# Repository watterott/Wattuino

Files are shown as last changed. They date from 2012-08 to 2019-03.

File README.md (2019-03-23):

# Wattuino
Arduino compatible Boards and Modules.

* [Wattuino Board Support Package](https://learn.watterott.com/arduino/watterott-boards) for Arduino IDE.
* [Documentation on learn.watterott.com](https://learn.watterott.com)
* Open-Source and released under the [Creative Commons Attribution Share-Alike License](https://creativecommons.org/licenses/by-sa/4.0/).

## Wattuino RC
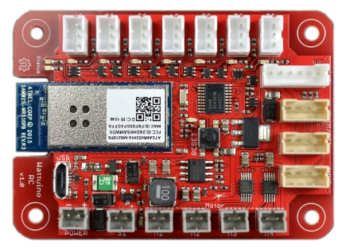
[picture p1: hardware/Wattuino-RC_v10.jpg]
Wattuino RC

* Microchip **SAMW25** Module (SAMD21 ARM Cortex-M0+ and WINC1500 WiFi/WLAN SoC)
* USB CDC+MSC Bootloader (Arduino compatible)
* 5V tolerant IOs
* Dual Full-Bridge Motor Drivers (Allegro Micro A3909)
* MicroUSB connector for programming/communication
* PCB Size: 70mm x 50mm

## Wattuino Uno
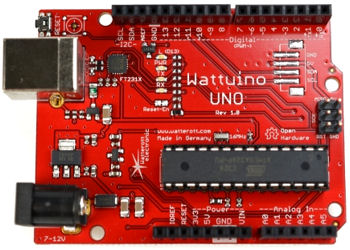
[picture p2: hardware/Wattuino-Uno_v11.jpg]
Wattuino Uno

* Microchip AVR **ATmega328P** @ 16 MHz (external resonator)
* OptiBoot Bootloader with auto baud rate detection (Arduino compatible)
* FTDI FT231X USB-UART-Bridge
* USB-B or MicroUSB connector for programming/communication
* PCB Size: 68.58mm x 53.34mm

## Wattuino Pro Mini
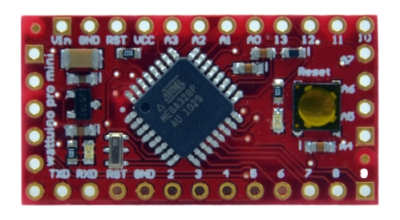
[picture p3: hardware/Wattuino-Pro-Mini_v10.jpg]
Wattuino Pro Mini

* Microchip AVR **ATmega328P** @ 16 MHz or 8 MHz (external resonator)
* OptiBoot Bootloader with auto baud rate detection (Arduino compatible)
* All pins of the AVR are available (also ADC6, ADC7)
* FTDI connector for programming/communication
* PCB Size: 33.02mm x 17.78mm

## Wattuino Pro Mini PB
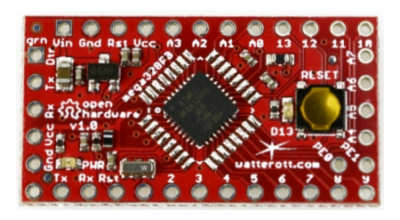
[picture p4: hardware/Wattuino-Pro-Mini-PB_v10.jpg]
Wattuino Pro Mini PB

* Microchip AVR **ATmega328PB** @ 16 MHz or 8 MHz (external resonator)
* OptiBoot Bootloader with auto baud rate detection (Arduino compatible)
* All pins of the AVR are available (also PE0/SDA1, PE1/SCL1, PE2/ADC6, PE3/ADC7)
* FTDI connector for programming/communication
* PCB Size: 33.02mm x 17.78mm

## Wattuino Nanite 841
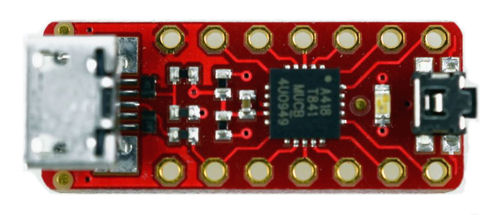
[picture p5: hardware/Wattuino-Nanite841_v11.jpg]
Wattuino Nanite841

* Microchip AVR **ATtiny841** @ 8 MHz (internal clock) with USART, SPI, I2C Slave, ADC, EEPROM
* Micronucleus USB Bootloader (Arduino compatible)
* Designed by [cpldcpu](https://github.com/cpldcpu)
* 14-Pin DIP and pin-compatible with 14-Pin SOIC ATtiny841
* MicroUSB connector for programming/communication
* PCB Size: 24.13mm x 10.16mm

## Wattuino Nanite 85
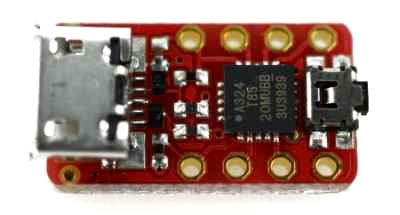
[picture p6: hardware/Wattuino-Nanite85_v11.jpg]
Wattuino Nanite85

* Microchip AVR **ATtiny85** @ 16.5 MHz (internal clock) with USI, ADC, EEPROM
* Micronucleus USB Bootloader (Arduino compatible)
* Based on the original [Nanite 85](https://github.com/cpldcpu/Nanite) design by [cpldcpu](https://github.com/cpldcpu)
* Pin-compatible with 8-Pin DIP ATtiny85
* MicroUSB connector for programming/communication
* PCB Size: 17.46mm x 10.16mm

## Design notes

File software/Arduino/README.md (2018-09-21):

# Watterott Board Support Package

Boards Package moved to (uninstall the old package before installing the new one):

```
https://github.com/watterott/Arduino-Boards/raw/master/package_watterott_index.json
```

Further infos:
https://learn.watterott.com/arduino/watterott-boards/

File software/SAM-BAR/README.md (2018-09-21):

# SAM-BAR
SAM-BAR (**S**mart **A**tmel **M**icrocontroller **B**oot **A**ssistant **R**eloaded) is a Combo USB CDC+MSD Bootloader for Atmel/Microchip SAM D21 devices (ARM Cortex-M0+).
It is based on the following bootloaders:
* [SAM-BA (AppNote AT07175) by Atmel/Microchip (www.atmel.com)](http://www.atmel.com/images/Atmel-42366-SAM-BA-Bootloader-for-SAM-D21_ApplicationNote_AT07175.zip)
* [Arduino Zero Bootloader by Arduino LLC (www.arduino.cc)](https://github.com/arduino/ArduinoCore-samd/tree/master/bootloaders/zero)
* [SAMD-MSD-Bootloader by Justin Mattair (www.mattairtech.com)](https://github.com/mattairtech/SAMD-MSD-Bootloader)

## Features
* SAM-BA and Arduino Zero compatible Bootloader (USB CDC/VCP)
* Mass-Storage-Device Bootloader (USB MSD/MSC)
* Fits in 16KB (user program start at 0x4000)

## Programming
The bootloader can be flashed with an ARM SWD (Serial Wire Debug) programmer.
To protect the bootloader flash section the fuse ```NVMCTRL_BOOTPROT``` has to be set to ```0x01```.

## Activation
The bootloader will be activated if no user program exists or by doing two reset in 0.5s (double pressing reset switch).
It can also be activated via an Arduino Sketch, when opening the serial port with 1200bps. This will erase the user program and start the bootloader.

## Usage
When the bootloader is active then a new program can be loaded via the serial port (SAM-BA protocol) or via the mass storage device.
For the mass storage device delete the file ```FLASH.BIN``` and then copy a new binary file ```FLASH.BIN``` to the drive.
After the copy process is finished, do a reset to start the new program.

On Linux/Mac the dd command can be used to write the firmware: ```dd if=NEW.BIN of=/media/BOOTLOADER/FLASH.BIN conv=notrunc```

A binary file can be generated and exported in the Arduino IDE with *Sketch->Export compiled Binary* command.

## Known Issues

### Windows
Sometimes the driver for the USB Bootloader is not loaded correctly.
Check the driver state in the Device Manager, when the Bootloader is active (double press reset).

### Linux
The Modem Manager can cause problems, because it detects Serial Ports (e.g. of the USB Bootloader) as a modem.
So we recommend to uninstall/remove the Modem Manager:
```
sudo apt-get uninstall modemmanager
```
As alternative it is also possible to add a backlist rule for the USB device to the file ```77-mm-usb-device-blacklist.rules```.

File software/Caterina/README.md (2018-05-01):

# Caterina

[Caterina](https://github.com/arduino/Arduino/tree/master/hardware/arduino/avr/bootloaders/caterina) is a small USB bootloader designed for Atmel AVR microcontrollers with USB interface (ATmega32u4).
It is based on the [LUFA library](http://www.lufa-lib.org).

The Caterina project is released under MIT license.
Code uploaded via the bootloader is not subject to any license issues.

**Credits**
```
* Arduino.cc Team
* LUFA (c) Dean Camera (dean [at] fourwalledcubicle [dot] com), www.lufa-lib.org
```

## USB Vendor and Product ID
* VID: 0x1D50 - [Openmoko](http://wiki.openmoko.org/wiki/USB_Product_IDs) + PID: 0x60B0 - [Watterott](http://wiki.openmoko.org/wiki/USB_Product_IDs)

## ISP Pins of ATmega32U4
```
MOSI: PB2
MISO: PB3
SCK:  PB1
RST:  Reset
```

## Fuse Settings for ATmega32U4
```
Extended: 0xCB
High:     0xD8
Low:      0xFF
Lockbits: 0xCF (LPM and SPM prohibited in Boot Section)
```

## AVRdude Parameters for ATmega32U4
```
avrdude -c avrisp2 -B 10 -p atmega32u4 -e -U flash:w:caterina_16mhz.hex:i -U lfuse:w:0xFF:m -U hfuse:w:0xD8:m -U efuse:w:0xCB:m -U lock:w:0xCF:m
```

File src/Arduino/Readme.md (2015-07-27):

# Watterott Board Support Package
Board Support Package for Arduino IDE >=1.6

## Automatic Installation

Add the following URL to the Arduino Boards Manager:
```
https://github.com/watterott/wattuino/raw/master/src/Arduino/package_watterott_index.json
```
and install the Watterott Boards via the Boards Manager.

## Manual Installation

Download https://github.com/watterott/wattuino/raw/master/src/Arduino/Arduino.zip and copy the directory "hardware" to your Arduino program directory.

## Known Issues

### Windows
Sometimes the driver for the USB Bootloader (Caterina or Micronucleus) is not loaded correctly.
This is the case when *Done uploading.* is not shown after the upload process.
Check the driver state in the Device Manager, when the Bootloader is active (Caterina after the *Upload* is started and Micronucleus after a reset).
On Windows 8 or higher the [driver signature enforcement](https://learn.sparkfun.com/tutorials/disabling-driver-signature-on-windows-8/disabling-signed-driver-enforcement-on-windows-8) has to be disabled for the driver installation.
* [Caterina Driver](https://github.com/watterott/wattuino/raw/master/src/Caterina/Caterina.inf)
* [Micronucleus Driver](https://github.com/watterott/wattuino/raw/master/src/Micronucleus/driver/driver.zip)
* [FTDI Drivers](http://www.ftdichip.com/Drivers/VCP.htm)

### Linux
The Modem Manager detects the Serial Ports (e.g. Caterina Bootloader) as a modem and therefore a blacklist rule is needed.
Run one of the commands - depending on your system:

```sudo nano /etc/udev/rules.d/77-mm-usb-device-blacklist.rules```
    
```sudo nano /lib/udev/rules.d/77-mm-usb-device-blacklist.rules```
    
and add the following lines to the file:

```
ATTRS{idVendor}=="6666", ENV{ID_MM_DEVICE_IGNORE}="1"
ATTRS{idVendor}=="1D50", ATTRS{idProduct}=="60B0", ENV{ID_MM_DEVICE_IGNORE}="1"
```

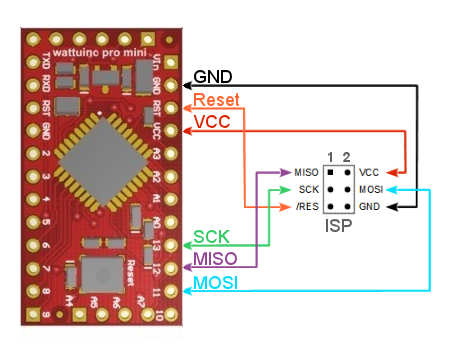
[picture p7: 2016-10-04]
hardware/Wattuino-Pro-Mini_ISP.jpg

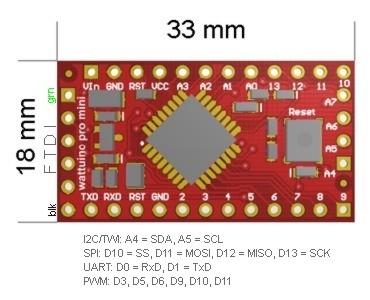
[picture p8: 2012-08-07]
hardware/Wattuino-Pro-Mini_Pins.jpg

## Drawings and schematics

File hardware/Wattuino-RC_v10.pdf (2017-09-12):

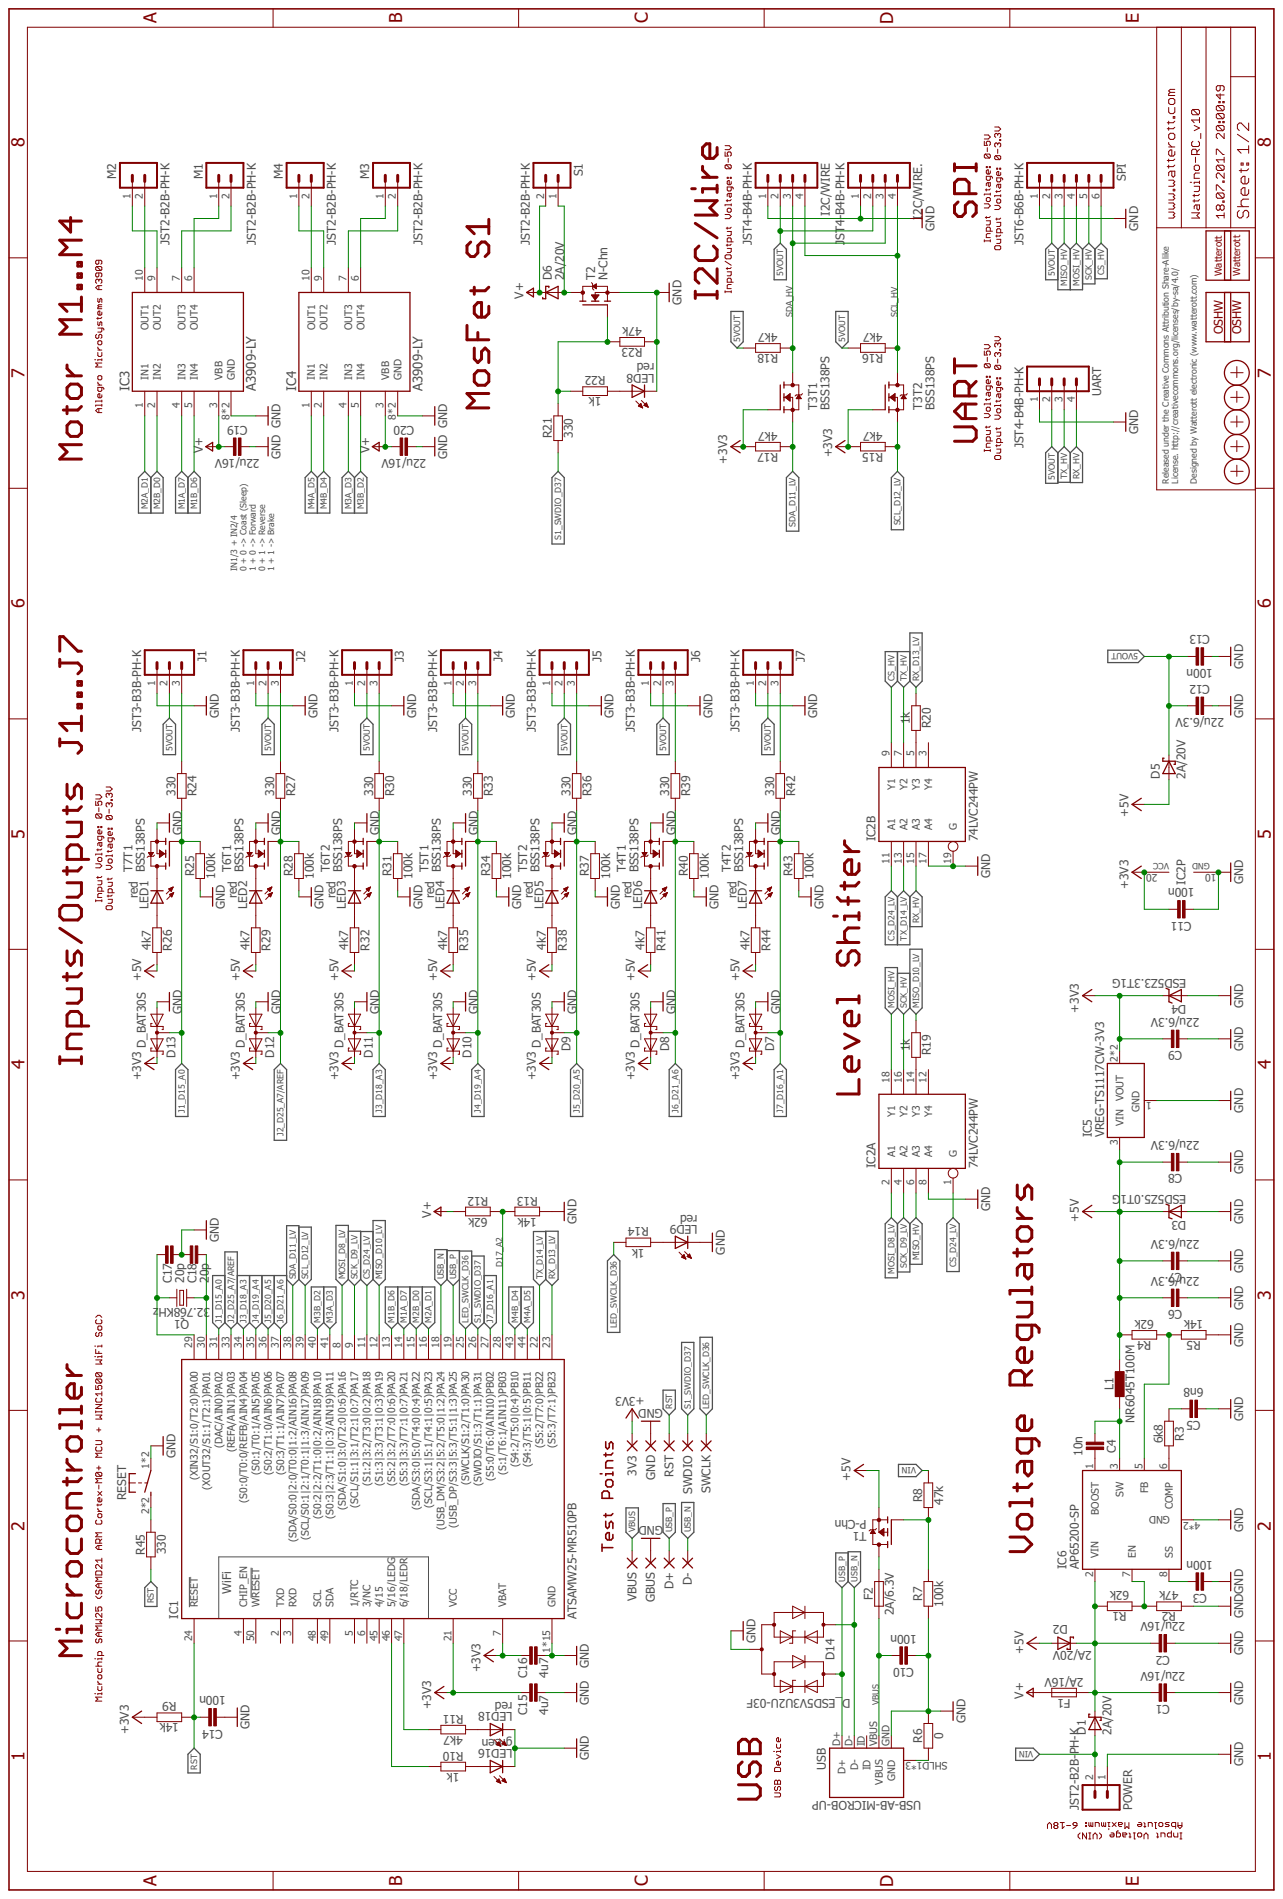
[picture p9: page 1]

Released under the Creative Commons At ribution Share-Alike

License. ht p://creativecommons.org/licenses/by-sa/4.0/ Designed by Wat erot electronic (www.wat erot .com)

GND GND GND GND GND

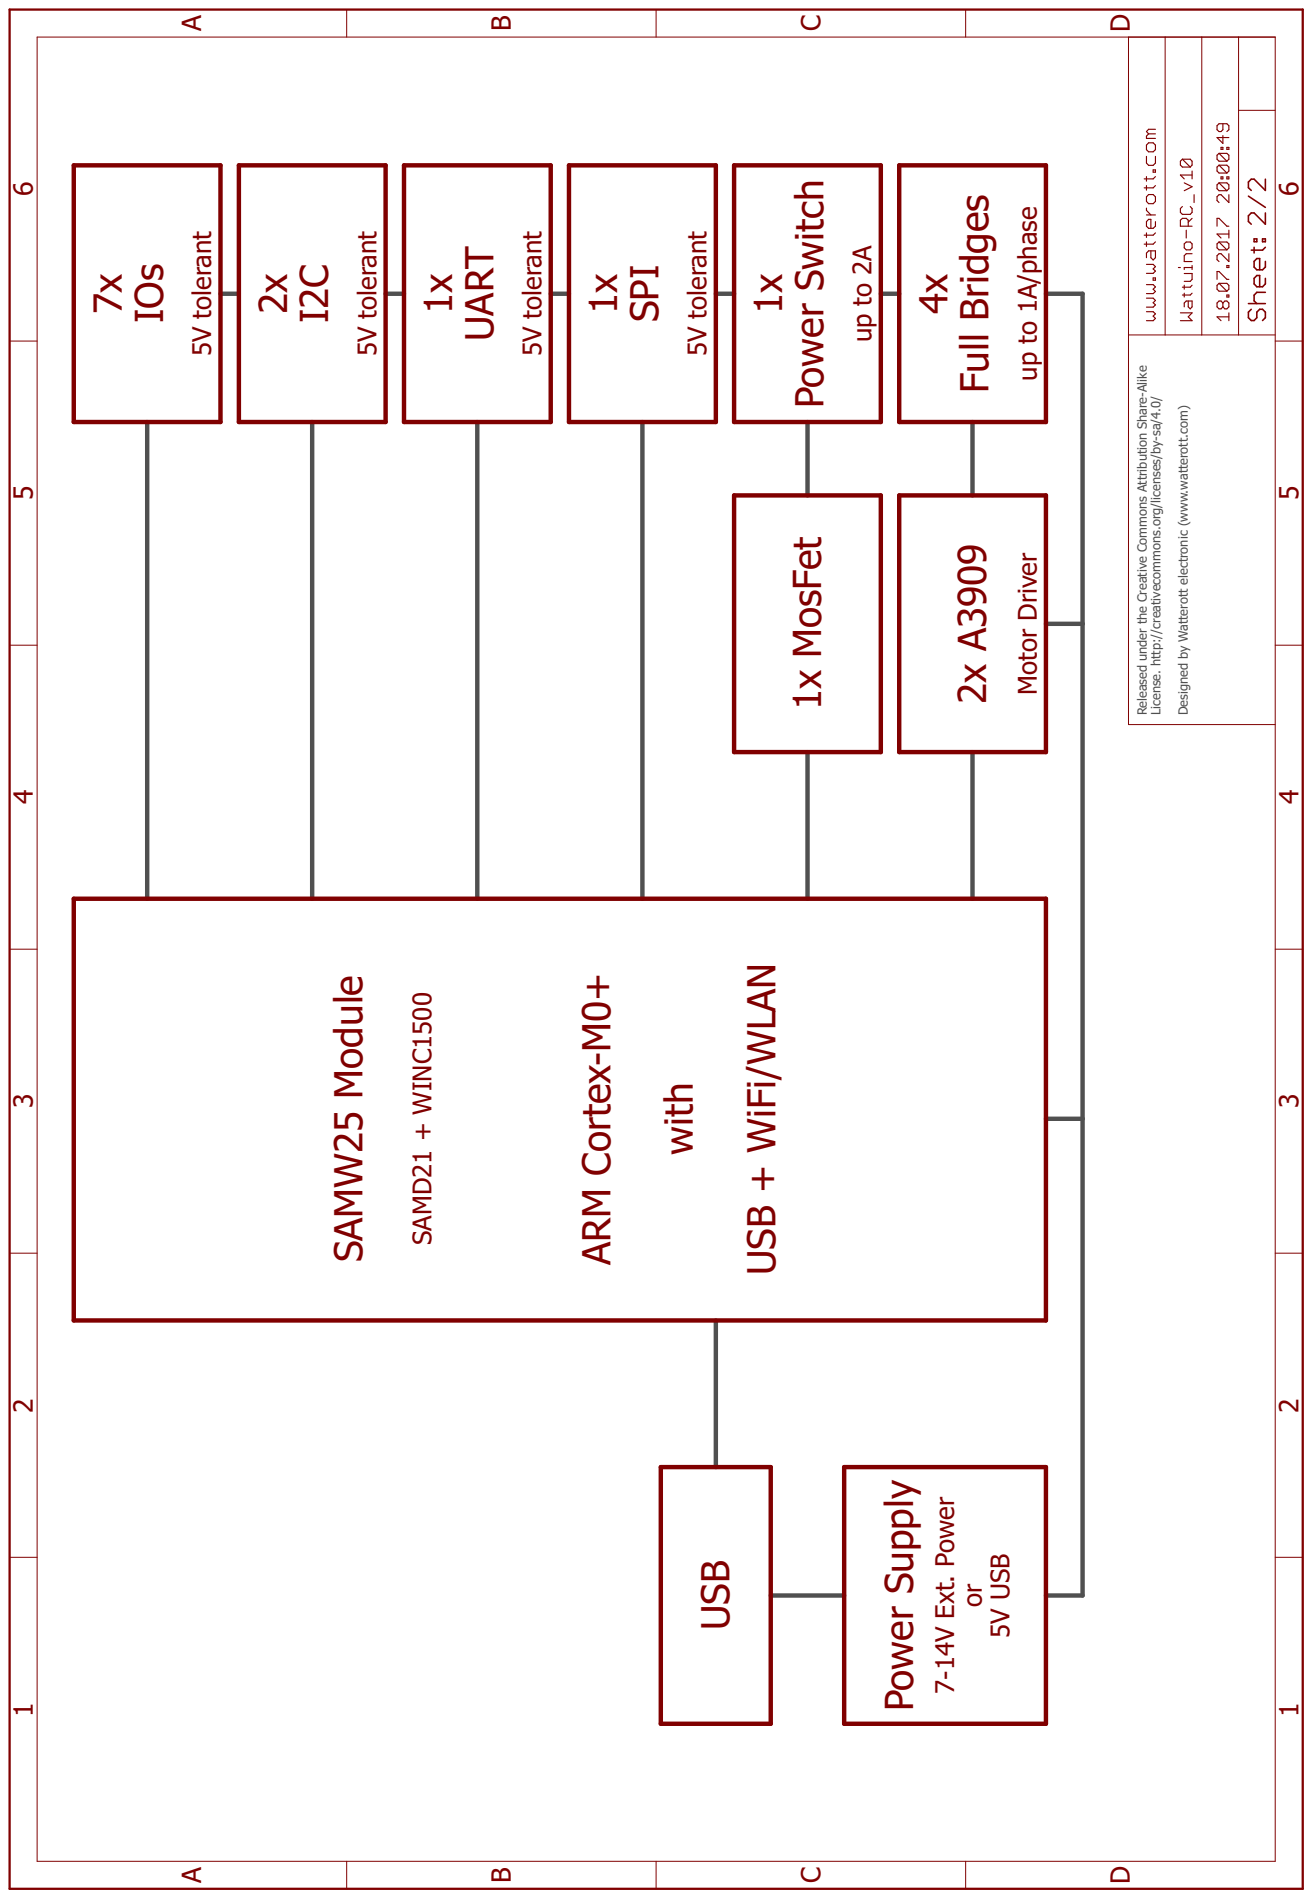
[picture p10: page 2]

Released under the Creative Commons At ribution Share-Alike License. http://creativecommons.org/licenses/by-sa/4.0/ Designed by Watterott electronic (www.watterott.com) SAMD21 + WINC1500 SAMW25 Module USB ARM Cortex-M0+ with USB + WiFi/WLAN 2x A3909 Motor Driver 7x IOs 2x I2C1x UART 1x SPI 4x Full Bridges 1x Power Switch 1x MosFet Power Supply 7-14V Ext. Power or 5V USB 5V tolerant 5V tolerant 5V tolerant 5V tolerant up to 2A up to 1A/phase ABCD 1 2 3 4 5 6 ABCD 1 2 3 4 5 6

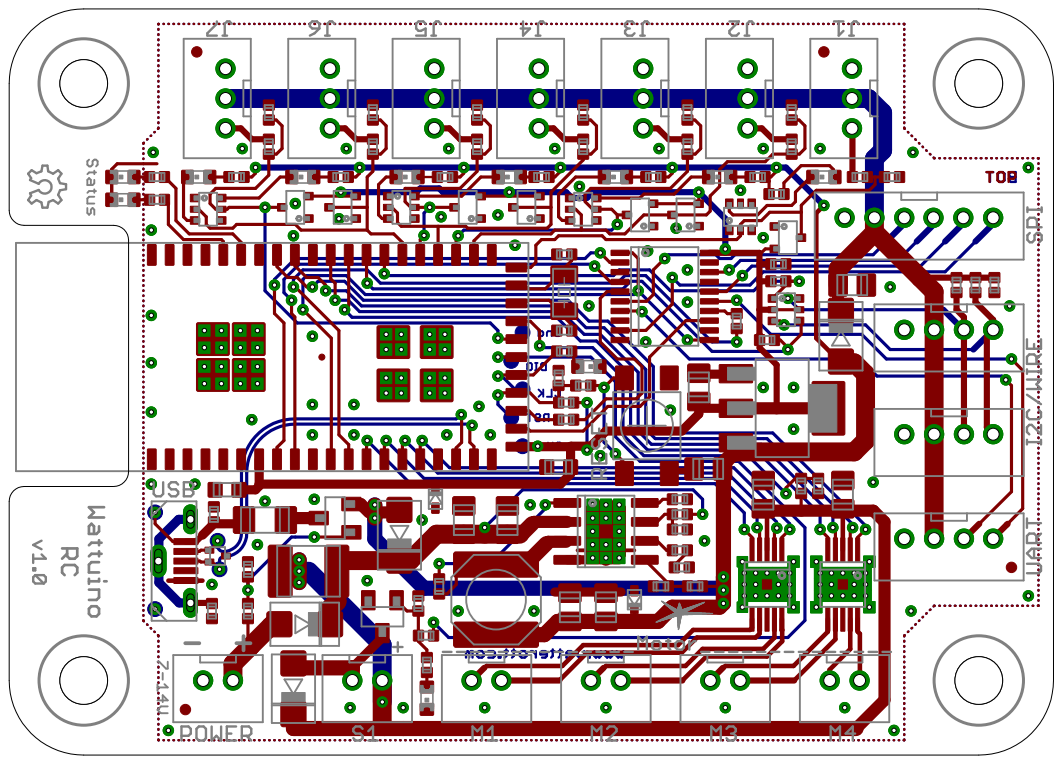
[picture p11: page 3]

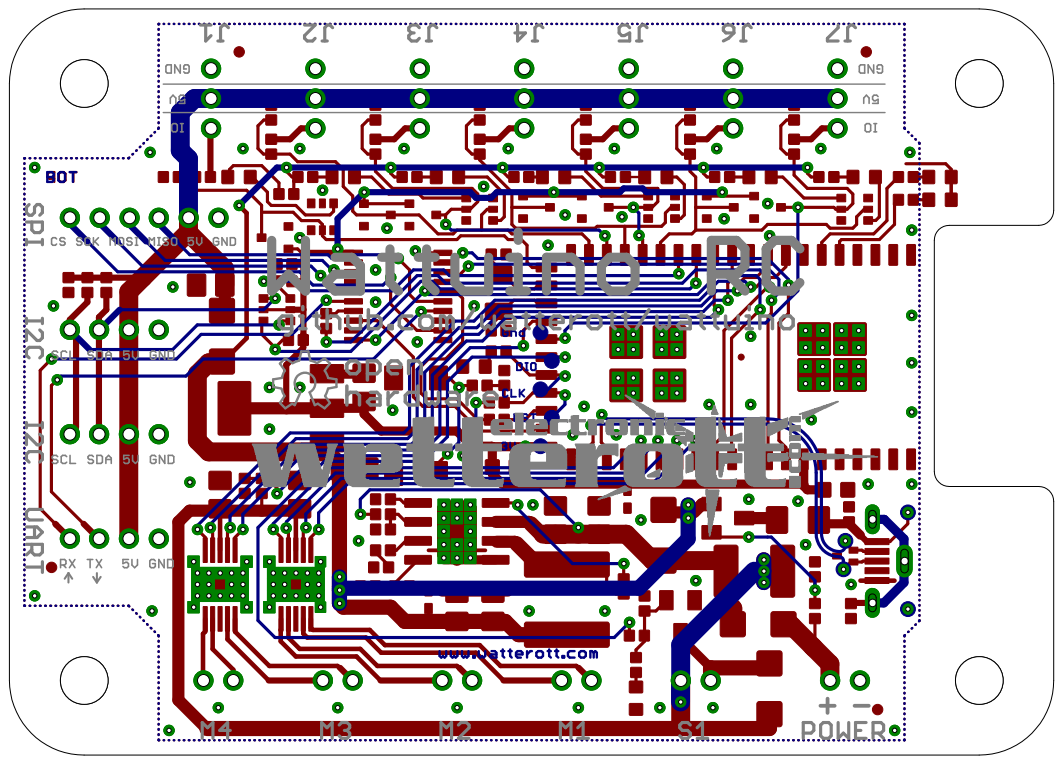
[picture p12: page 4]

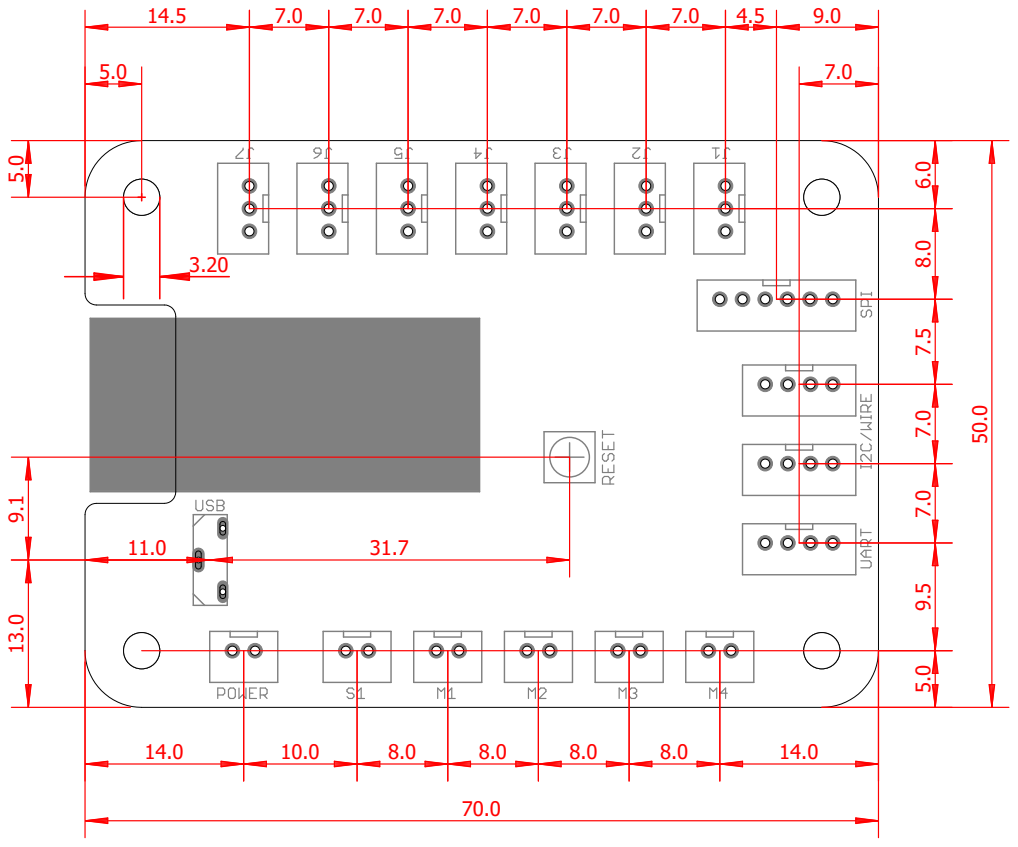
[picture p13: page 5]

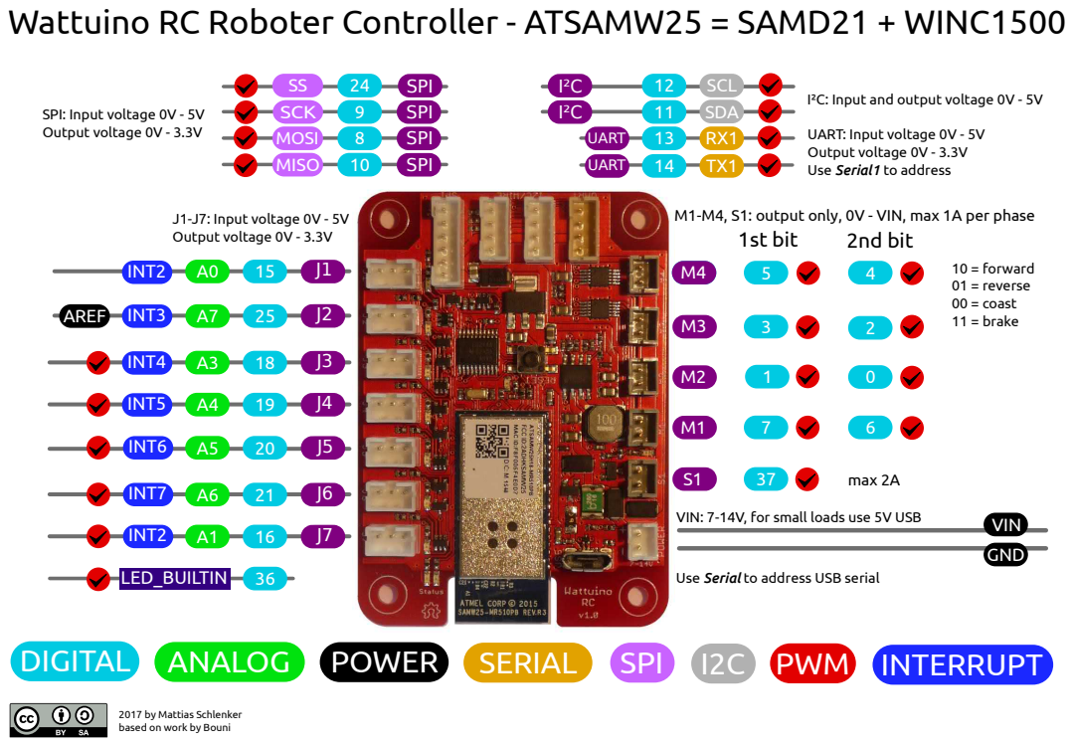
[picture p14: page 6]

Wattuino RC Roboter Controller - ATSAMW25 = SAMD21 + WINC1500

I²C: Input and output voltage 0V - 5V

M1-M4, S1: output only, 0V - VIN, max 1A per phase

VIN: 7-14V, for small loads use 5V USB

Use Serial to address USB serial

2017 by Mattias Schlenker
based on work by Bouni

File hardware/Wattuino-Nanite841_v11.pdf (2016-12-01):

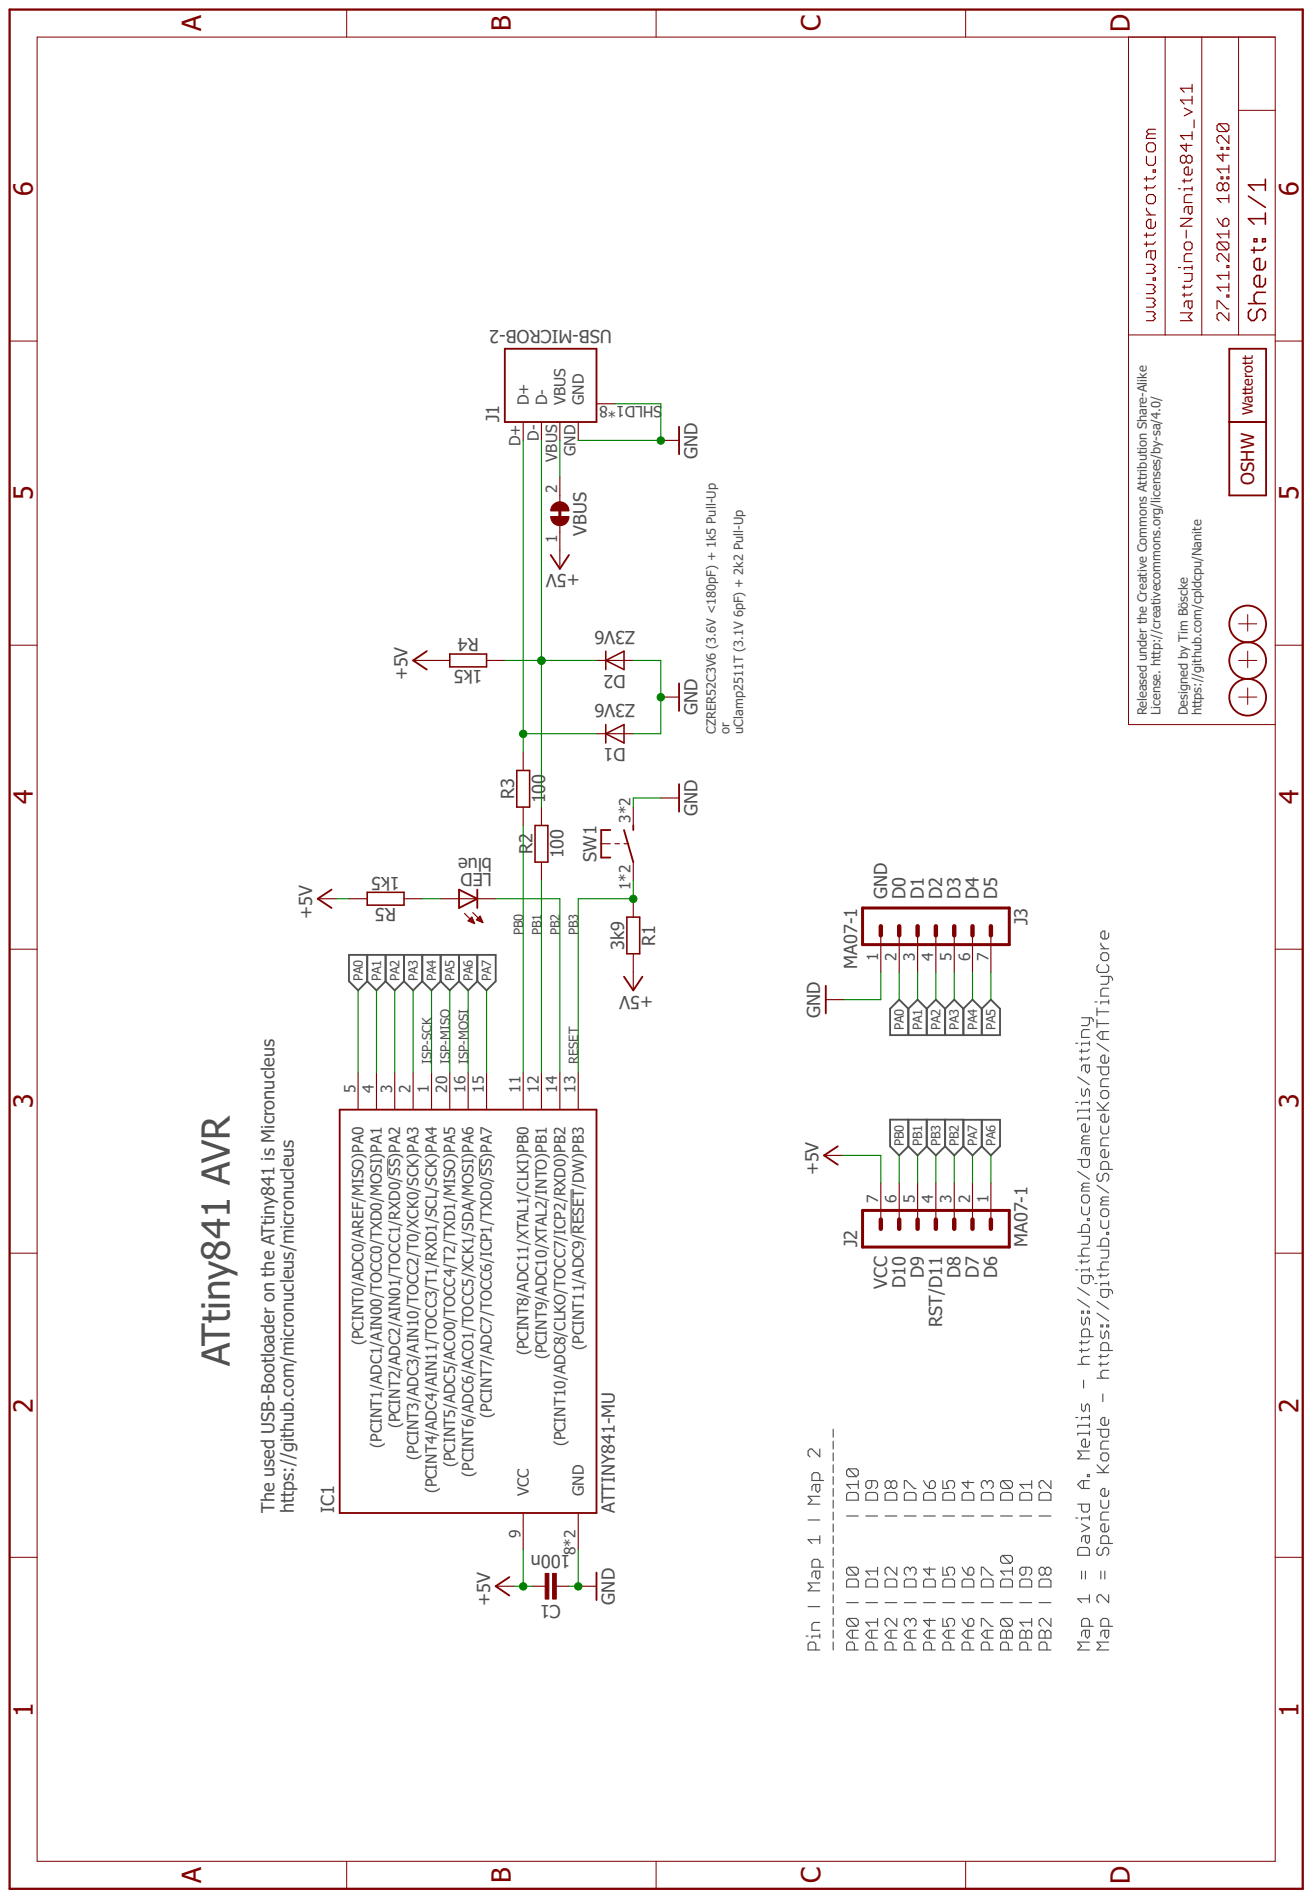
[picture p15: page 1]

The used USB-Bootloader on the ATtiny841 is Micronucleus https://github.com/micronucleus/micronucleus CZRER52C3V6 (3.6V <180pF) + 1k5 Pull-Up or uClamp2511T (3.1V 6pF) + 2k2 Pull-Up ATtiny841 AVR GND D0D1D2D3D4D5 VCC D10D9 RST/D11D8D7D6 RESET ISP-MOSI ISP-MISO ISP-SCK n001 100 100 GND GND 5k1 GND V5 + +5V 3k9 V5 + 6V3Z 6V3Z GND+5V +5V GND MA07-1 MA07-1 AT INY841-MU eul b 5k1 +5V Released under the Creative Commons At ribution Share-Alike License. http://creativecommons.org/licenses/by-sa/4.0/ Designed by Tim Böscke https://github.com/cpldcpu/Nanite 1C D+ D+ D- D- VBUS VBUS GND GND J1 2- BORCI M- BSU8*1DL HS R3 R2 4R 2 1VBUS R1 2D1D J2 7654321 J3 1234567 (PCINT0/ADC0/AREF/MISO)PA0 5 (PCINT1/ADC1/AIN00/TOCC0/TXD0/MOSI)PA1 4 (PCINT2/ADC2/AIN01/TOCC1/RXD0/SS)PA2 3 (PCINT3/ADC3/AIN10/TOCC2/T0/XCK0/SCK)PA3 2 (PCINT4/ADC4/AIN11/TOCC3/T1/RXD1/SCL/SCK)PA4 1 (PCINT5/ADC5/ACO0/TOCC4/T2/TXD1/MISO)PA5 20 (PCINT6/ADC6/ACO1/TOCC5/XCK1/SDA/MOSI)PA6 16 (PCINT7/ADC7/TOCC6/ICP1/TXD0/SS)PA7 15 (PCINT8/ADC11/XTAL1/CLKI)PB0 11 (PCINT9/ADC10/XTAL2/INTO)PB1 12 (PCINT10/ADC8/CLKO/TOCC7/ICP2/RXD0)PB2 14 (PCINT11/ADC9/RESET/DW)PB3 13 GND 8*2 VCC 9 IC1 DEL 5R SW1 1*2 3*2 PB0 PB0 PB1 PB1 PB3 PB3 PB2 PB2 PA7 PA7 PA6 PA6 PA5 PA5 PA4 PA4 PA3 PA3 PA2 PA2 PA1 PA1 PA0 PA0 OSHW Watterott ABCD 1 2 3 4 5 6 ABCD 1 2 3 4 5 6

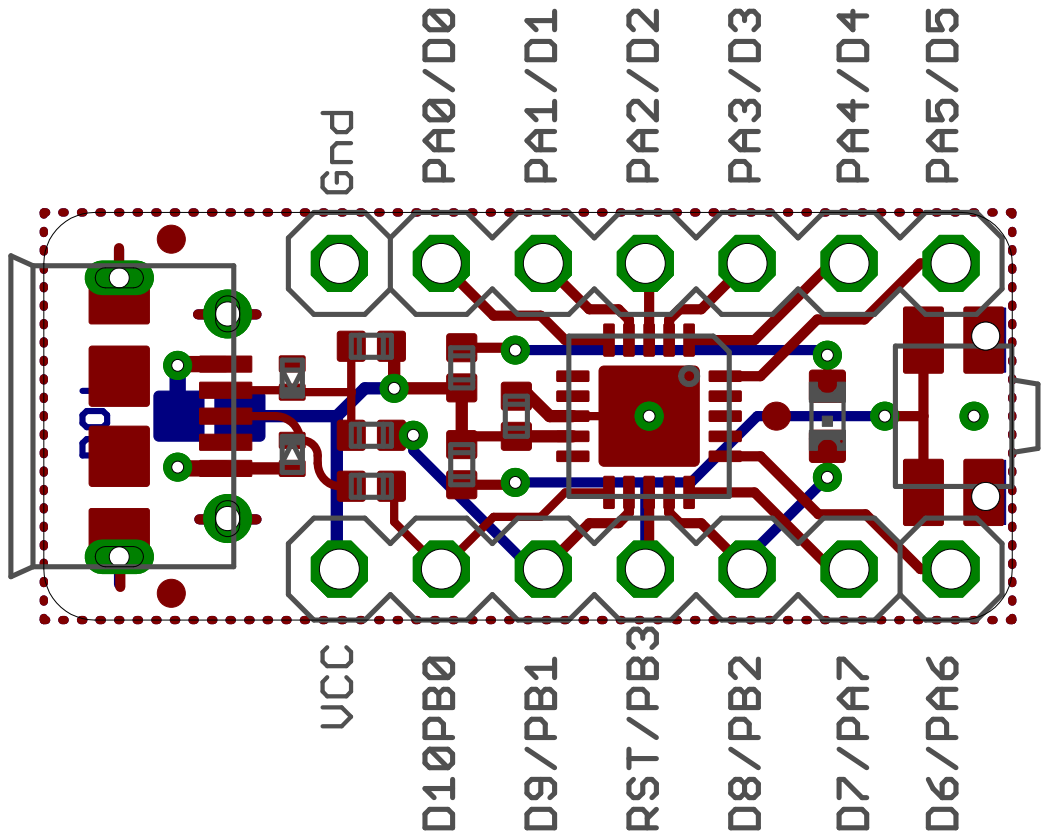
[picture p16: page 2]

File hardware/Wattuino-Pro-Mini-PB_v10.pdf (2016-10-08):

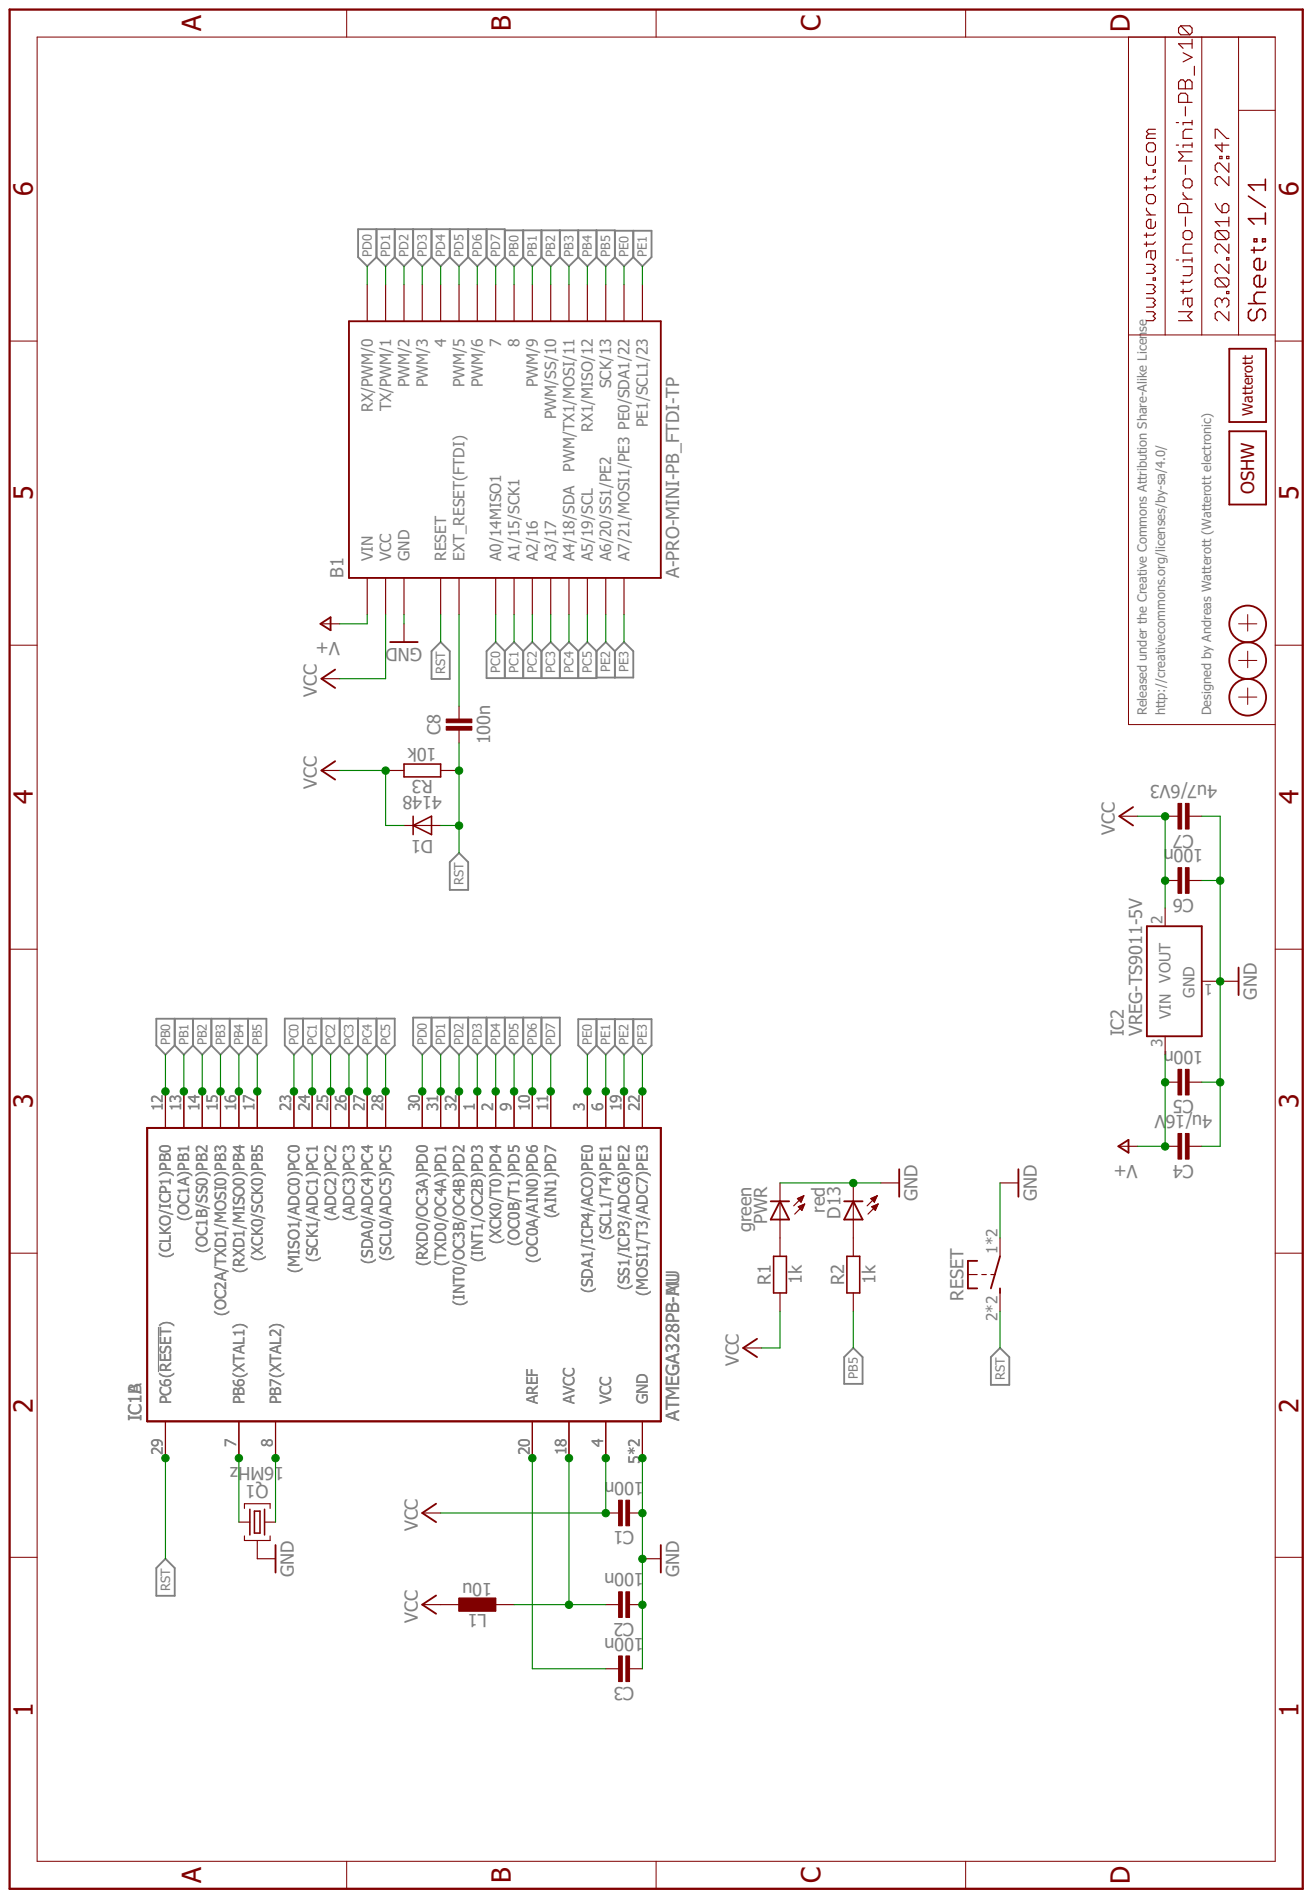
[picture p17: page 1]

ATMEGA328PB-AU DNG VCC VCC A-PRO-MINI-PB_FTDI-TP z HM61 VREG-TS9011-5V n001 n001 3V6/ 7u4 n001 n001 u01 VCC GND V61/ u4 1k1k green redGND GND +V +V VCC ATMEGA328PB-MU 100n k01 8414 VCC VCC GND n001 GND Released under the Creative Commons Attribution Share-Alike License http://creativecommons.org/licenses/by-sa/4.0/ Designed by Andreas Watterott (Watterott electronic) IC1A (XCK0/SCK0)PB5 17 PB7(XTAL2) 8 PB6(XTAL1) 7 VCC 4 GND 5*2 AREF 20 AVCC 18 (RXD1/MISO0)PB4 16 (OC2A/TXD1/MOSI0)PB3 15 (OC1B/SS0)PB2 14 (OC1A)PB1 13 (CLKO/ICP1)PB0 12 (AIN1)PD7 11 (OC0A/AIN0)PD6 10 (OC0B/T1)PD5 9 (XCK0/T0)PD4 2 (INT1/OC2B)PD3 1 (INT0/OC3B/OC4B)PD2 32 (TXD0/OC4A)PD1 31 (RXD0/OC3A)PD0 30 (SCL0/ADC5)PC5 28 (SDA0/ADC4)PC4 27 (ADC3)PC3 26 (ADC2)PC2 25 (SCK1/ADC1)PC1 24 (MISO1/ADC0)PC0 23 PC6(RESET) 29 (SDA1/ICP4/ACO)PE0 3 (SCL1/T4)PE1 6 (SS1/ICP3/ADC6)PE2 19 (MOSI1/T3/ADC7)PE3 22 B1 RX/PWM/0 TX/PWM/1 PWM/2 PWM/34 PWM/5 PWM/678 PWM/9 VIN GND VCC A2/16 A1/15/SCK1 A0/14MISO1 SCK/13 RX1/MISO/12 PWM/TX1/MOSI/11 PWM/SS/10 EXT_RESET(FTDI) A7/21/MOSI1/PE3 A6/20/SS1/PE2 A5/19/SCL A4/18/SDA A3/17 RESET PE0/SDA1/22 PE1/SCL1/23 1 Q IC2 GND VIN 3 V1 OUT 2 5C6C7C 2C3C 1L 4C R1R2 PWR D13 IC1B (XCK0/SCK0)PB5 17 PB7(XTAL2) 8 PB6(XTAL1) 7 VCC 4 GND 5*2 AREF 20 AVCC 18 (RXD1/MISO0)PB4 16 (OC2A/TXD1/MOSI0)PB3 15 (OC1B/SS0)PB2 14 (OC1A)PB1 13 (CLKO/ICP1)PB0 12 (AIN1)PD7 11 (OC0A/AIN0)PD6 10 (OC0B/T1)PD5 9 (XCK0/T0)PD4 2 (INT1/OC2B)PD3 1 (INT0/OC3B/OC4B)PD2 32 (TXD0/OC4A)PD1 31 (RXD0/OC3A)PD0 30 (SCL0/ADC5)PC5 28 (SDA0/ADC4)PC4 27 (ADC3)PC3 26 (ADC2)PC2 25 (SCK1/ADC1)PC1 24 (MISO1/ADC0)PC0 23 PC6(RESET) 29 (SDA1/ICP4/ACO)PE0 3 (SCL1/T4)PE1 6 (SS1/ICP3/ADC6)PE2 19 (MOSI1/T3/ADC7)PE3 22 C8 3R1D RESET1*2 2*2 1CPE3 PE3 PE2 PE2 PE1 PE1 PE0 PE0 PD7 PD7 PD6 PD6 PD5 PD5 PD4 PD4 PD3 PD3 PD2 PD2 PD1 PD1 PD0 PD0 PB0 PB0 PB1 PB1 PB2 PB2 PB3 PB3 PB4 PB4 PB5 PB5 PB5 PC0 PC0 PC1 PC1 PC2 PC2 PC3 PC3 PC4 PC4 PC5 PC5 RST RST RST RST ABCD 1 2 3 4 5 6 ABCD 1 2 3 4 5 6 OSHW Watterott

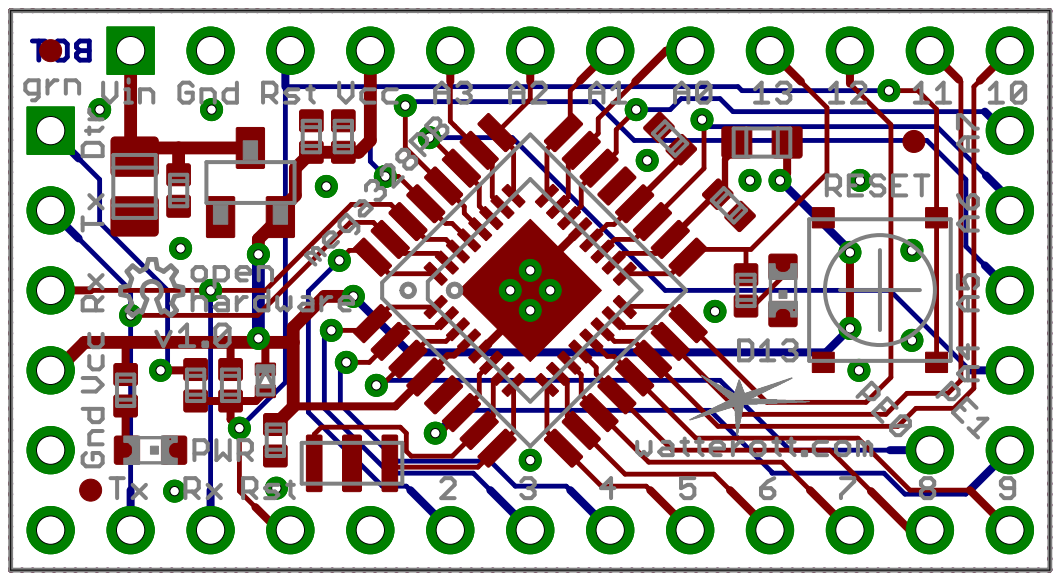
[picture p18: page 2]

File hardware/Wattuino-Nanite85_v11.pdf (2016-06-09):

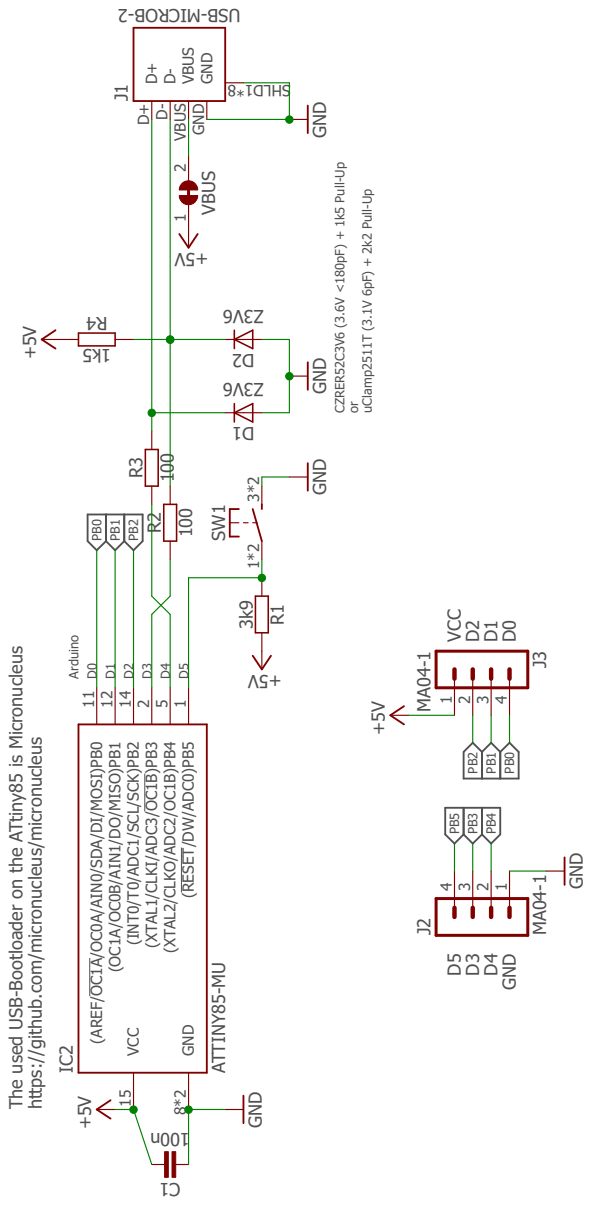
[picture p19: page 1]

The used USB-Bootloader on the ATtiny85 is Micronucleus ht ps://github.com/micronucleus/micronucleus CZRER52C3V6 (3.6V <180pF) + 1k5 Pull-Up or uClamp2511T (3.1V 6pF) + 2k2 Pull-Up Arduino D0D1D2D3D4D5 D0D1D2 D5D3D4 GND VCC n001 AT INY85-MU 100 100 GND GND 5k1 GND V5 + +5V 3k9 V5 + 6V3Z 6V3Z GND+5V MA04-1 MA04-1 +5V GND Released under the Creative Commons At ribution Share-Alike License. ht p://creativecommons.org/licenses/by-sa/4.0/ Designed by Stephan Wat erot (Wat erot electronic) Based on the original Nanite 85 design by Tim Böscke ht ps://github.com/cpldcpu/Nanite 1C IC2 (RESET/DW/ADC0)PB5 1 VCC 15 GND 8*2 (XTAL2/CLKO/ADC2/OC1B)PB4 5 (XTAL1/CLKI/ADC3/OC1B)PB3 2 (INT0/T0/ADC1/SCL/SCK)PB2 14 (OC1A/OC0B/AIN1/DO/MISO)PB1 12 (AREF/OC1A/OC0A/AIN0/SDA/DI/MOSI)PB0 11 D+ D+ D- D- VBUS VBUS GND GND J1 2- BORCI M- BSU8*1DL HS R3 R2 4R 2 1VBUS R1 2D1D J2 4321 J3 1234 SW1 1*2 3*2 PB3 PB4 PB0 PB0 PB2 PB2 PB1 PB1 PB5 OSHW Watterott ABCD 1 2 3 4 5 6 ABCD 1 2 3 4 5 6

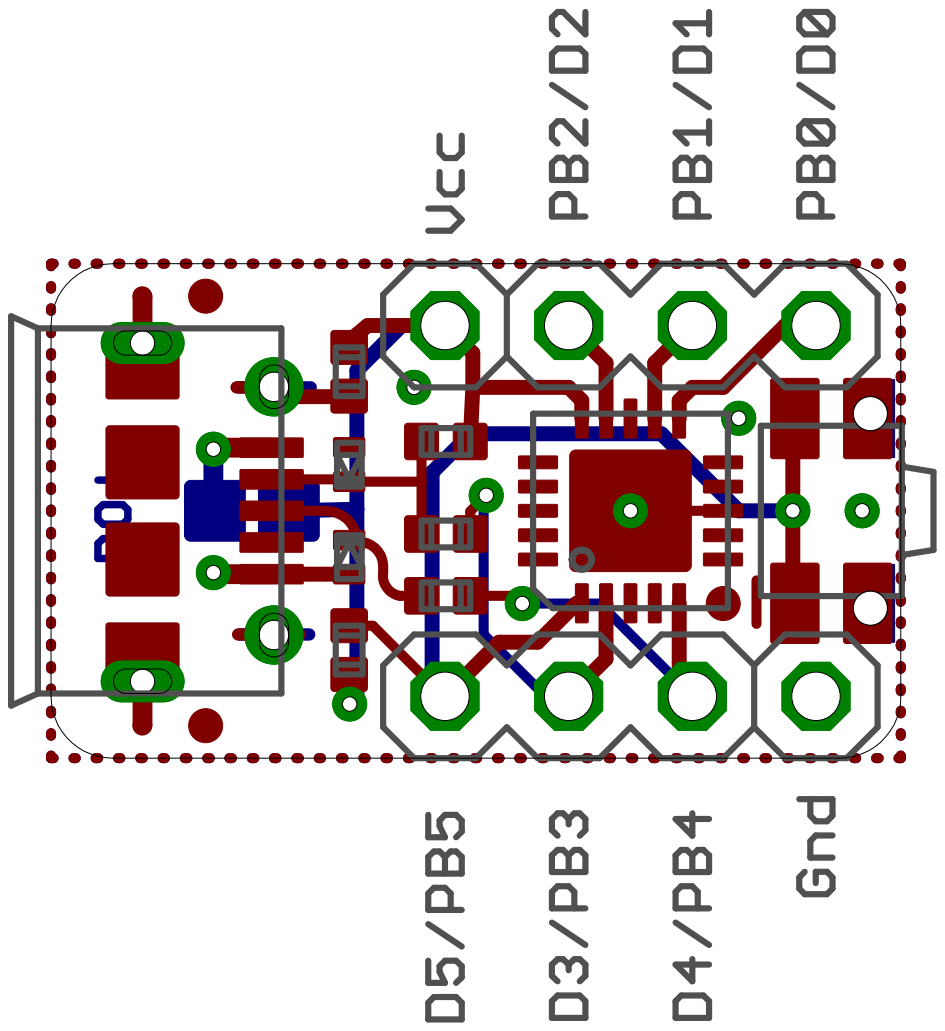
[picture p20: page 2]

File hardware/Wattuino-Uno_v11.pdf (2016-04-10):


8 PWM/9 PWM/SS/10 PWM/MOSI/11 MISO/12 SCK/13 AIN1 AIN2 AIN3 AIN4/SDA

10k Released under the Creative Commons Attribution Share-Alike

Inspired by the original Arduino Uno design - http://arduino.cc

License. http://creativecommons.org/licenses/by-sa/4.0/ Designed by Andreas Watterott (Watterott electronic)




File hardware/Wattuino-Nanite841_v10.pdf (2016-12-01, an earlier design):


The used USB-Bootloader on the ATtiny841 is Micronucleus https://github.com/micronucleus/micronucleus CZRER52C3V6 (3.6V <180pF) + 1k5 Pull-Up or uClamp2511T (3.1V 6pF) + 2k2 Pull-Up ATtiny841 AVR GND D0D1D2D3D4D5 VCC D10D9 RST/D11D8D7D6 ISP-SCK ISP-MISO ISP-MOSI RESET n001 100 100 GND GND 5k1 GND V5 + +5V 3k9 V5 + 6V3Z 6V3Z GND+5V +5V GND MA07-1 MA07-1 AT INY841-MU eul b 5k1 +5V Released under the Creative Commons At ribution Share-Alike License. http://creativecommons.org/licenses/by-sa/4.0/ Designed by Tim Böscke https://github.com/cpldcpu/Nanite 1C D+ D+ D- D- VBUS VBUS GND GND J1 ORCI M- BSU2*1DL HS R3 R2 4R 2 1VBUS R1 2D1D SW1 1 34 2 J2 7654321 J3 1234567 (PCINT0/ADC0/AREF/MISO)PA0 5 (PCINT1/ADC1/AIN00/TOCC0/TXD0/MOSI)PA1 4 (PCINT2/ADC2/AIN01/TOCC1/RXD0/SS)PA2 3 (PCINT3/ADC3/AIN10/TOCC2/T0/XCK0/SCK)PA3 2 (PCINT4/ADC4/AIN11/TOCC3/T1/RXD1/SCL/SCK)PA4 1 (PCINT5/ADC5/ACO0/TOCC4/T2/TXD1/MISO)PA5 20 (PCINT6/ADC6/ACO1/TOCC5/XCK1/SDA/MOSI)PA6 16 (PCINT7/ADC7/TOCC6/ICP1/TXD0/SS)PA7 15 (PCINT8/ADC11/XTAL1/CLKI)PB0 11 (PCINT9/ADC10/XTAL2/INTO)PB1 12 (PCINT10/ADC8/CLKO/TOCC7/ICP2/RXD0)PB2 14 (PCINT11/ADC9/RESET/DW)PB3 13 GND 8*2 VCC 9 IC1 DEL 5R PB0 PB0 PB1 PB1 PB3 PB3 PB2 PB2 PA7 PA7 PA6 PA6 PA5 PA5 PA4 PA4 PA3 PA3 PA2 PA2 PA1 PA1 PA0 PA0 OSHW Watterott ABCD 1 2 3 4 5 6 ABCD 1 2 3 4 5 6


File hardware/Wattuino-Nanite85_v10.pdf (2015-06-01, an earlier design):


The used USB-Bootloader on the ATtiny85 is Micronucleus https:/ github.com/micronucleus/micronucleus CZRER52C3V6 (3.6V <180pF) + 1k5 Pull-Up or uClamp2511T (3.1V 6pF) + 2k2 Pull-Up Arduino D0 D1 D2 D3 D4 D5 D0D1D2 D5D3D4 GND VCC n001 ATTINY85-MU 100 100 GND GND 5k1 GND V5+ +5V 3k9 V5+ 6V3Z 6V3Z GND+5V MA04-1 MA04-1 +5V GND Released under the Creative Commons Attribution Share-Alike License http://creativecommons.org/licenses/by-sa/4.0/ Designed by Stephan Watterott (Watterott electronic) Based on the original Nanite 85 design by Tim Böscke https://github.com/cpldcpu/Nanite 1C IC2 (RESET/DW/ADC0)PB5 1 VCC 15 GND 8*2 (XTAL2/ADC2/OC1B)PB4 5 (XTAL1/ADC3/OC1B)PB3 2 (INT0/T0/ADC1/SCL/SCK)PB2 14 (OC1A/OC0B/AIN1/DO/MISO)PB1 12 (AREF/OC1A/OC0A/AIN0/SDA/DI/MOSI)PB0 11 D+ D+ D- D- VBUS VBUS GND GNDJ1 ORCI M- BSU2* 1DLHS R3 R2 4R 2 1VBUS R1 2D1D J2 4321 J3 1234 SW1 1 34 2 PB3 PB4 PB0 PB0 PB2 PB2 PB1 PB1 PB5 OSHW LOGO Logo ABCD 1 2 3 4 5 6 ABCD 1 2 3 4 5 6


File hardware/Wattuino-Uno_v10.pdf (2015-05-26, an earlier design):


10k Released under the Creative Commons Attribution Share-Alike License

Inspired by the original Arduino Uno design - http://arduino.cc

Designed by Andreas Watterott (Watterott electronic)

http://creativecommons.org/licenses/by-sa/4.0/

(MISO)PB4 18 (OC2A/MOSI)PB3 17 (SS/OC1B)PB2 16 (OC1A)PB1 15 (CLKO/ICP1)PB0 14


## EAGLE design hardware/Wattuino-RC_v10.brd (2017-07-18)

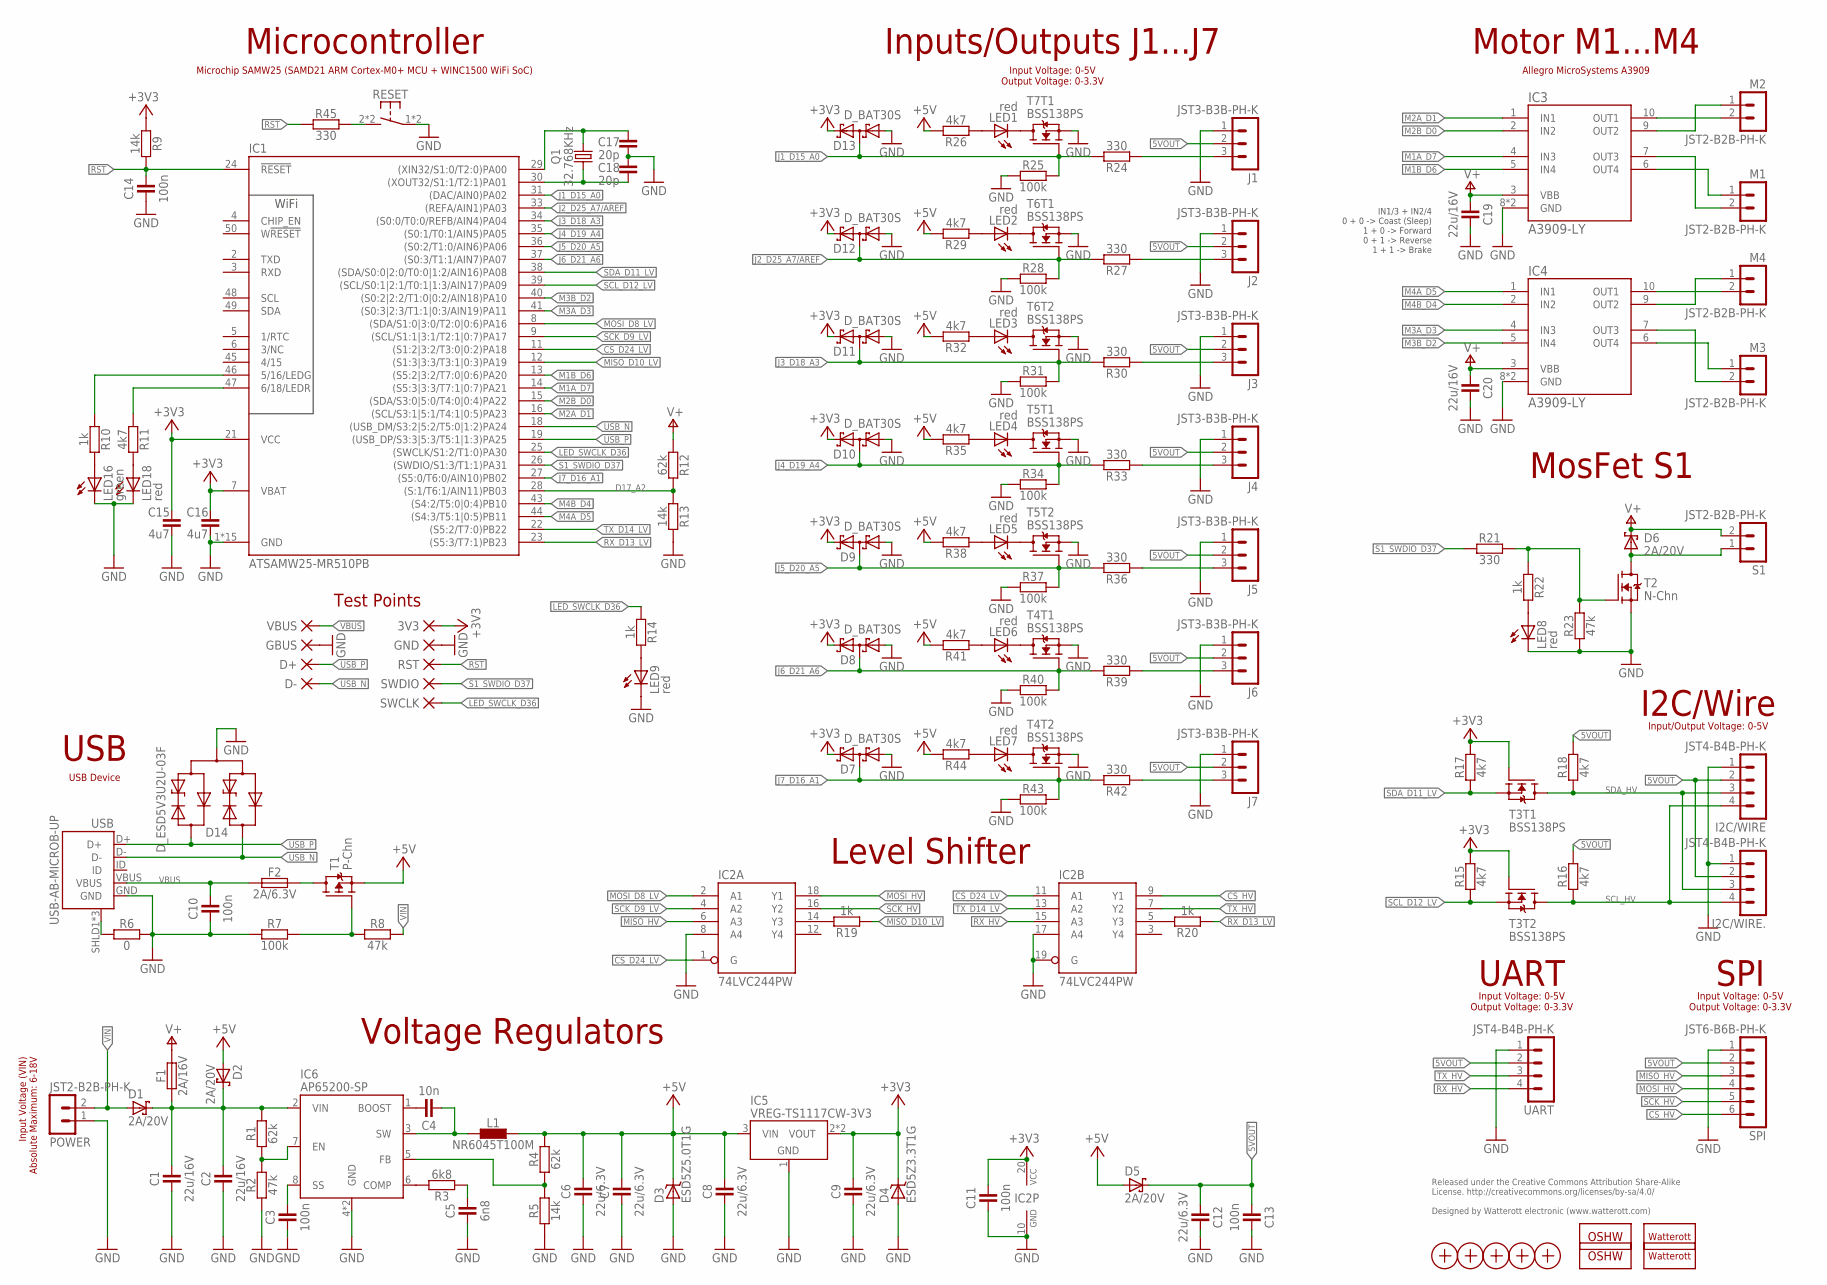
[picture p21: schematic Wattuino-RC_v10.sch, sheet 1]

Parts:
3V3: PAD-1.0_NC
C1, C2, C19, C20: 22u/16V; C0805
C3, C10, C11, C13, C14: 100n; C0402
C4: 10n; C0402
C5: 6n8; C0402
C6, C7, C8, C9, C12: 22u/6.3V; C0805
C15, C16: 4u7; C0603
C17, C18: 20p; C0402
D1, D2, D5, D6: 2A/20V; SMA_DO214AC
D3: ESD5Z5.0T1G; SOD523
D4: ESD5Z3.3T1G; SOD523
D7, D8, D9, D10, D11, D12, D13: D_BAT30S; SOT323
D14: D_ESD5V3U2U-03F; SOT723
D+: PAD-1.0_NC
D-: PAD-1.0_NC
F1: 2A/16V; C1812
F2: 2A/6.3V; C1206
GBUS: PAD-1.0_NC
GND: PAD-1.0_NC
I2C/WIRE, I2C/WIRE.: JST4-B4B-PH-K; JST_B4B-PH-K
IC1: ATSAMW25-MR510PB; ATSAMW25-MRX10
IC2: 74LVC244PW; TSSOP20
IC3, IC4: A3909-LY; MSOP10-PAD
IC5: VREG-TS1117CW-3V3; SOT223
IC6: AP65200-SP; SO08-PAD
J1, J2, J3, J4, J5, J6, J7: JST3-B3B-PH-K; JST_B3B-PH-K
L1: NR6045T100M; L_NR60XX
LED1, LED2, LED3, LED4, LED5, LED6, LED7, LED8, LED9, LED18: red; C0603
LED16: green; C0603
LOGO1: OSHW_LOGOX0100; OSHW_6X100
LOGO2: OSHW_LOGOX0150; OSHW_6X150
LOGO3: LOGO-S_PLACE_S; SPARK_TPLACE_S
LOGO4: LOGO-PLACE; LOGO_TPLACE
M1, M2, M3, M4: JST2-B2B-PH-K; JST_B2B-PH-K
POWER: JST2-B2B-PH-K; JST_B2B-PH-K
Q1: 32.768KHz; CRYSTAL_ZM315
R1, R4, R12: 62k; C0402
R2, R8, R23: 47k; C0402
R3: 6k8; C0402
R5, R9, R13: 14k; C0402
R6: 0; C0402
R7, R25, R28, R31, R34, R37, R40, R43: 100k; C0402
R10, R14, R19, R20, R22: 1k; C0402
R11, R15, R16, R17, R18, R26, R29, R32, R35, R38, R41, R44: 4k7; C0402
R21, R24, R27, R30, R33, R36, R39, R42, R45: 330; C0402
RESET: SW-TACTILE-TL3305C; TL3305; MPN TL3305C
RST: PAD-1.0_NC
S1: JST2-B2B-PH-K; JST_B2B-PH-K
SPI: JST6-B6B-PH-K; JST_B6B-PH-K
SWCLK: PAD-1.0_NC
SWDIO: PAD-1.0_NC
T1: P-Chn; SOT23
T2: N-Chn; SOT23
T3, T4, T5, T6, T7: BSS138PS; SOT363
UART: JST4-B4B-PH-K; JST_B4B-PH-K
USB: USB-AB-MICROB-UP; USB-MICROB-1051330011
VBUS: PAD-1.0_NC
X1, X2, X3, X4: PASSER-07; PASSER_07MM
X5: PASSER-04; PASSER_04MM

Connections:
5VOUT: C12.2, C13.2, D5.C, I2C/WIRE.2, I2C/WIRE..2, J1.2, J2.2, J3.2, J4.2, J5.2, J6.2, J7.2, R16.2, R18.2, SPI.2, UART.2
+3V3: 3V3.1, C9.2, C11.2, C15.2, C16.2, D4.C, D7.2 (C), D8.2 (C), D9.2 (C), D10.2 (C), D11.2 (C), D12.2 (C), D13.2 (C), IC1.7 (VBAT), IC1.21 (VCC), IC2.20 (VCC), IC5.2 (VOUT), IC5.4 (VOUT), R9.1, R15.2, R17.2, T3.2 (G), T3.5 (G)
+5V: C6.2, C7.2, C8.2, D2.A, D3.C, D5.A, IC5.3 (VIN), L1.2, R4.2, R26.2, R29.2, R32.2, R35.2, R38.2, R41.2, R44.2, T1.2 (S)
BOOST: C4.2, IC6.1 (BOOST)
COMP: IC6.6 (COMP), R3.2
CS_D24_LV: IC1.11 ((S1:2|3:2/T3:0|0:2)PA18), IC2.1 (G), IC2.11 (A1)
CS_HV: IC2.9 (Y1), SPI.6
D17_A2: IC1.28 ((S:1/T6:1/AIN11)PB03), R12.2, R13.1
GND: C1.1, C2.1, C3.1, C5.1, C6.1, C7.1, C8.1, C9.1, C10.1, C11.1, C12.1, C13.1, C14.1, C15.1, C16.1, C17.2, C18.2, C19.2, C20.2, D3.A, D4.A, D7.1 (A), D8.1 (A), D9.1 (A), D10.1 (A), D11.1 (A), D12.1 (A), D13.1 (A), D14.3 (A), GBUS.1, GND.1, I2C/WIRE.1, I2C/WIRE..1, IC1.1 (GND), IC1.10 (GND), IC1.17 (GND), IC1.20 (GND), IC1.32 (GND), IC1.42 (GND), IC1.51 (GND), IC1.GND@1 (GND), IC1.GND@2 (GND), IC1.GND@3 (GND), IC1.GND@4 (GND), IC1.GND@5 (GND), IC1.GND@6 (GND), IC1.GND@7 (GND), IC1.GND@8 (GND), IC2.8 (A4), IC2.10 (GND), IC2.17 (A4), IC2.19 (G), IC3.8 (GND), IC3.TP (GND), IC4.8 (GND), IC4.TP (GND), IC5.1 (GND), IC6.4 (GND), IC6.TP (GND), J1.1, J2.1, J3.1, J4.1, J5.1, J6.1, J7.1, LED8.C, LED9.C, LED16.C, LED18.C, POWER.1 (2), R2.1, R5.1, R6.1, R7.1, R13.2, R23.1, R25.1, R28.1, R31.1, R34.1, R37.1, R40.1, R43.1, RESET.1, RESET.4 (P1), SPI.1, T2.2 (S), T4.1 (S), T4.4 (S), T5.1 (S), T5.4 (S), T6.1 (S), T6.4 (S), T7.1 (S), UART.1, USB.GND
IO16: IC1.46 (5/16/LEDG), R10.1
IO18: IC1.47 (6/18/LEDR), R11.1
J1_D15_A0: D13.3 (CA), IC1.31 ((DAC/AIN0)PA02), R24.2, R25.2, T7.2 (G)
J2_D25_A7/AREF: D12.3 (CA), IC1.33 ((REFA/AIN1)PA03), R27.2, R28.2, T6.2 (G)
J3_D18_A3: D11.3 (CA), IC1.34 ((S0:0/T0:0/REFB/AIN4)PA04), R30.2, R31.2, T6.5 (G)
J4_D19_A4: D10.3 (CA), IC1.35 ((S0:1/T0:1/AIN5)PA05), R33.2, R34.2, T5.2 (G)
J5_D20_A5: D9.3 (CA), IC1.36 ((S0:2/T1:0/AIN6)PA06), R36.2, R37.2, T5.5 (G)
J6_D21_A6: D8.3 (CA), IC1.37 ((S0:3/T1:1/AIN7)PA07), R39.2, R40.2, T4.2 (G)
J7_D16_A1: D7.3 (CA), IC1.27 ((S5:0/T6:0/AIN10)PB02), R42.2, R43.2, T4.5 (G)
LED_SWCLK_D36: IC1.25 ((SWCLK/S1:2/T1:0)PA30), R14.1, SWCLK.1
M1A_D7: IC1.14 ((S5:3|3:3/T7:1|0:7)PA21), IC3.4 (IN3)
M1B_D6: IC1.13 ((S5:2|3:2/T7:0|0:6)PA20), IC3.5 (IN4)
M1_O1: IC3.7 (OUT3), M1.2 (1)
M1_O2: IC3.6 (OUT4), M1.1 (2)
M2A_D1: IC1.16 ((SCL/S3:1|5:1/T4:1|0:5)PA23), IC3.1 (IN1)
M2B_D0: IC1.15 ((SDA/S3:0|5:0/T4:0|0:4)PA22), IC3.2 (IN2)
M2_O1: IC3.10 (OUT1), M2.2 (1)
M2_O2: IC3.9 (OUT2), M2.1 (2)
M3A_D3: IC1.41 ((S0:3|2:3/T1:1|0:3/AIN19)PA11), IC4.4 (IN3)
M3B_D2: IC1.40 ((S0:2|2:2/T1:0|0:2/AIN18)PA10), IC4.5 (IN4)
M3_O1: IC4.7 (OUT3), M3.2 (1)
M3_O2: IC4.6 (OUT4), M3.1 (2)
M4A_D5: IC1.44 ((S4:3/T5:1|0:5)PB11), IC4.1 (IN1)
M4B_D4: IC1.43 ((S4:2/T5:0|0:4)PB10), IC4.2 (IN2)
M4_O1: IC4.10 (OUT1), M4.2 (1)
M4_O2: IC4.9 (OUT2), M4.1 (2)
MISO_D10_LV: IC1.12 ((S1:3|3:3/T3:1|0:3)PA19), R19.1
MISO_HV: IC2.6 (A3), SPI.3
MISO_LV: IC2.14 (Y3), R19.2
MOSI_D8_LV: IC1.8 ((SDA/S1:0|3:0/T2:0|0:6)PA16), IC2.2 (A1)
MOSI_HV: IC2.18 (Y1), SPI.4
unnamed: LED8.A, R22.2
unnamed: J1.3, R24.1
unnamed: F2.2, T1.3 (D)
unnamed: R7.2, R8.1, T1.1 (G)
unnamed: LED9.A, R14.2
unnamed: R21.2, R22.1, R23.2, T2.1 (G)
unnamed: LED7.C, T4.3 (D)
unnamed: LED7.A, R44.1
unnamed: J7.3, R42.1
unnamed: C4.1, IC6.3 (SW), L1.1
unnamed: C3.2, IC6.8 (SS)
unnamed: J6.3, R39.1
unnamed: J5.3, R36.1
unnamed: J4.3, R33.1
unnamed: IC6.5 (FB), R4.1, R5.2
unnamed: LED6.C, T4.6 (D)
unnamed: LED6.A, R41.1
unnamed: J2.3, R27.1
unnamed: LED5.A, R38.1
unnamed: J3.3, R30.1
unnamed: LED4.A, R35.1
unnamed: LED4.C, T5.6 (D)
unnamed: LED5.C, T5.3 (D)
unnamed: LED3.A, R32.1
unnamed: LED2.A, R29.1
unnamed: LED2.C, T6.6 (D)
unnamed: LED3.C, T6.3 (D)
unnamed: LED1.A, R26.1
unnamed: LED1.C, T7.6 (D)
unnamed: C5.2, R3.1
unnamed: IC6.7 (EN), R1.1, R2.2
unnamed: LED18.A, R11.2
unnamed: LED16.A, R10.2
RST: C14.2, IC1.24 (!RESET), R9.2, R45.1, RST.1
RST_SW: R45.2, RESET.2 (S1), RESET.3 (S1)
RX_D13_LV: IC1.23 ((S5:3/T7:1)PB23), R20.1
RX_HV: IC2.15 (A3), UART.4
RX_LV: IC2.5 (Y3), R20.2
S1: D6.A, S1.1 (2), T2.3 (D)
S1_SWDIO_D37: IC1.26 ((SWDIO/S1:3/T1:1)PA31), R21.1, SWDIO.1
SCK_D9_LV: IC1.9 ((SCL/S1:1|3:1/T2:1|0:7)PA17), IC2.4 (A2)
SCK_HV: IC2.16 (Y2), SPI.5
SCL_D12_LV: IC1.39 ((SCL/S0:1|2:1/T0:1|1:3/AIN17)PA09), R15.1, T3.4 (S)
SCL_HV: I2C/WIRE.4, I2C/WIRE..4, R16.1, T3.3 (D)
SDA_D11_LV: IC1.38 ((SDA/S0:0|2:0/T0:0|1:2/AIN16)PA08), R17.1, T3.1 (S)
SDA_HV: I2C/WIRE.3, I2C/WIRE..3, R18.1, T3.6 (D)
SHLD1: R6.2, USB.SHLD1 (SHIELD), USB.SHLD2 (SHIELD), USB.SHLD3 (SHIELD)
TX_D14_LV: IC1.22 ((S5:2/T7:0)PB22), IC2.13 (A2)
TX_HV: IC2.7 (Y2), UART.3
USB_N: D14.1 (C1), D-.1, IC1.18 ((USB_DM/S3:2|5:2/T5:0|1:2)PA24), USB.D-
USB_P: D14.2 (C2), D+.1, IC1.19 ((USB_DP/S3:3|5:3/T5:1|1:3)PA25), USB.D+
V+: C19.1, C20.1, D6.C, F1.2, IC3.3 (VBB), IC4.3 (VBB), R12.1, S1.2 (1)
VBUS: C10.2, F2.1, USB.VBUS, VBUS.1
VIN: D1.A, POWER.2 (1), R8.2
VINP: C1.2, C2.2, D1.C, D2.C, F1.1, IC6.2 (VIN), R1.2
XIN: C17.1, IC1.29 ((XIN32/S1:0/T2:0)PA00), Q1.2
XOUT: C18.1, IC1.30 ((XOUT32/S1:1/T2:1)PA01), Q1.1

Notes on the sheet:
USB
Motor M1...M4
MosFet S1
I2C/Wire
UART
SPI
Inputs/Outputs J1...J7
Voltage Regulators
Microcontroller
Test Points
Released under the Creative Commons Attribution Share-Alike License. http://creativecommons.org/licenses/by-sa/4.0/ Designed by Watterott electronic (www.watterott.com)
Input Voltage (VIN) Absolute Maximum: 6-18V
Level Shifter
Input Voltage: 0-5V Output Voltage: 0-3.3V
Allegro MicroSystems A3909
Input/Output Voltage: 0-5V
Microchip SAMW25 (SAMD21 ARM Cortex-M0+ MCU + WINC1500 WiFi SoC)
IN1/3 + IN2/4 0 + 0 -> Coast (Sleep) 1 + 0 -> Forward 0 + 1 -> Reverse 1 + 1 -> Brake
USB Device

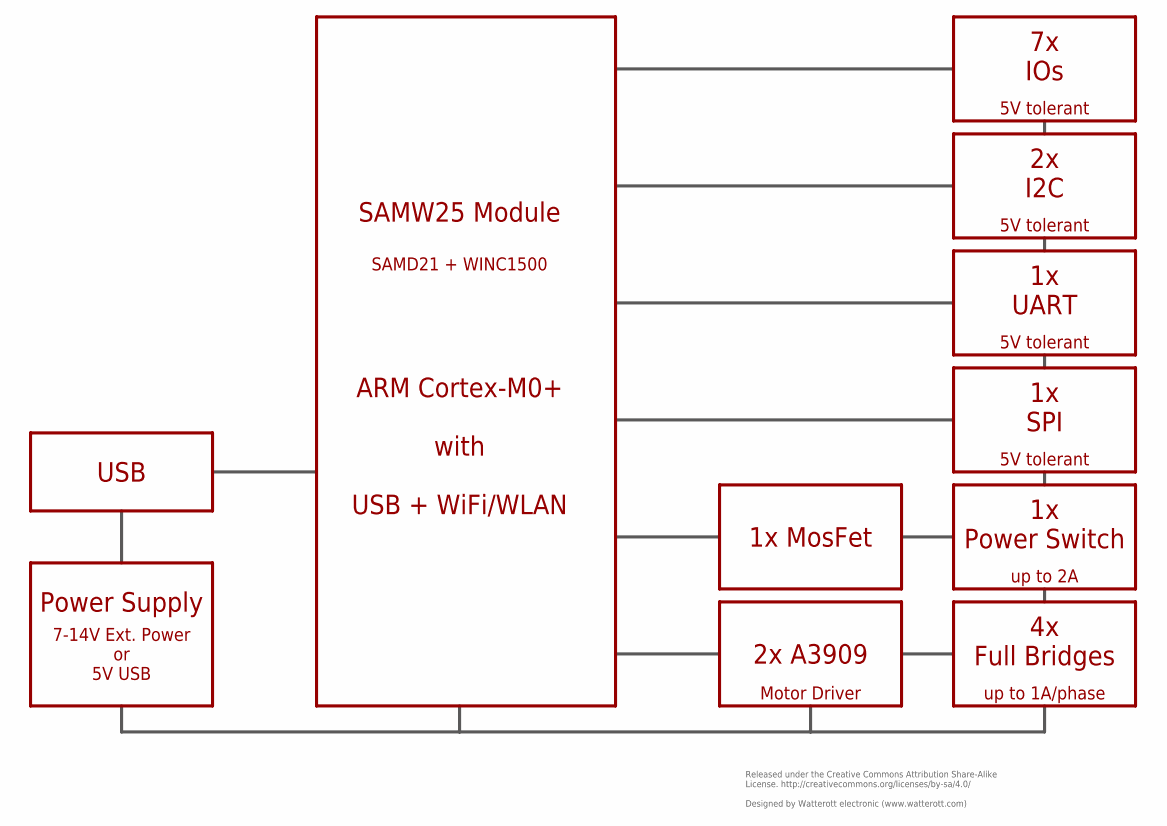
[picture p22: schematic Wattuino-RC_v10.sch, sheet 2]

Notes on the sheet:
SAMD21 + WINC1500
SAMW25 Module
USB
ARM Cortex-M0+ with USB + WiFi/WLAN
2x A3909
Motor Driver
7x IOs
2x I2C
1x UART
1x SPI
4x Full Bridges
1x Power Switch
1x MosFet
Power Supply
7-14V Ext. Power or 5V USB
5V tolerant
up to 2A
up to 1A/phase
Released under the Creative Commons Attribution Share-Alike License. http://creativecommons.org/licenses/by-sa/4.0/ Designed by Watterott electronic (www.watterott.com)

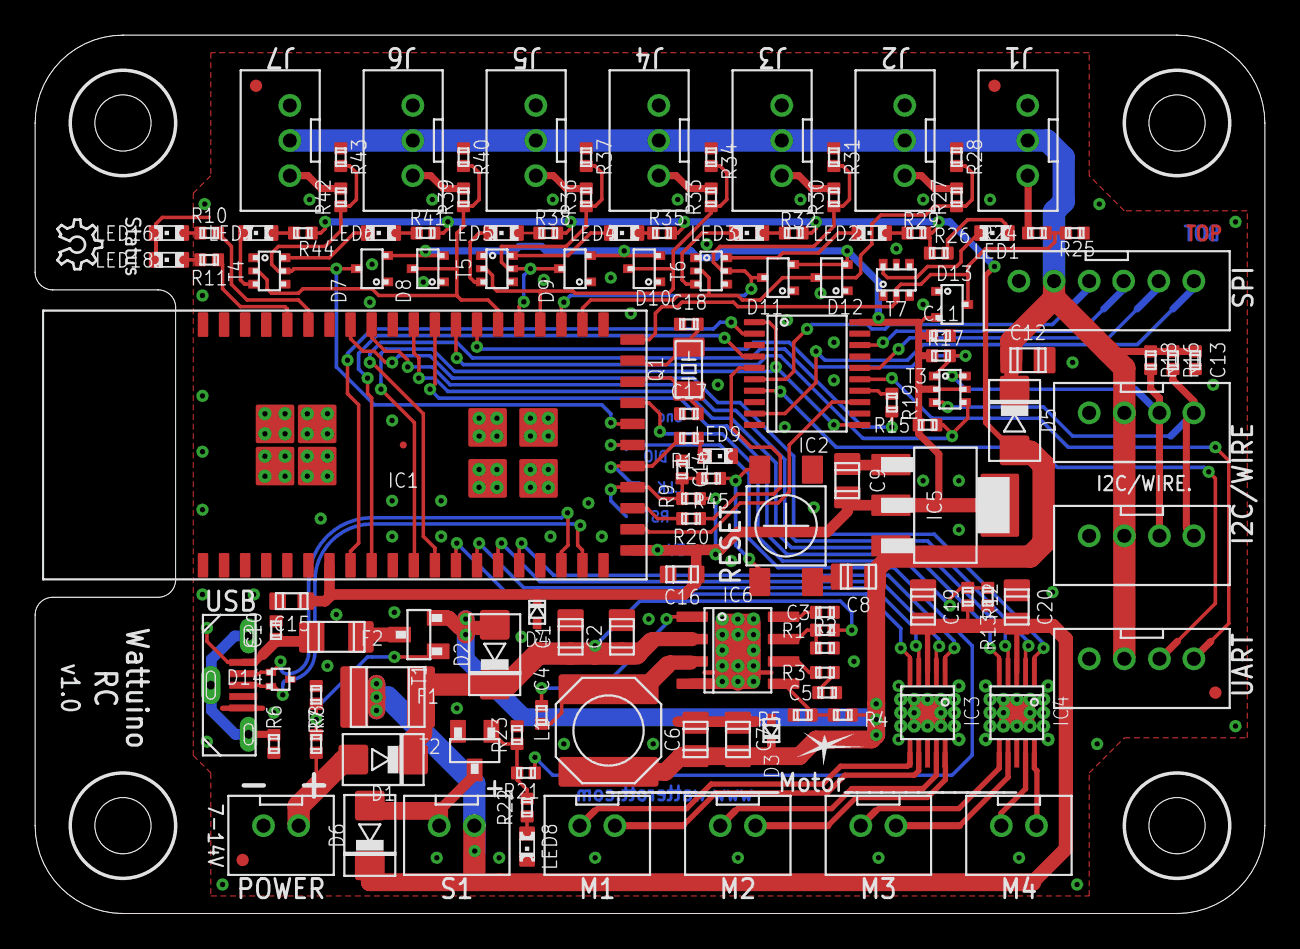
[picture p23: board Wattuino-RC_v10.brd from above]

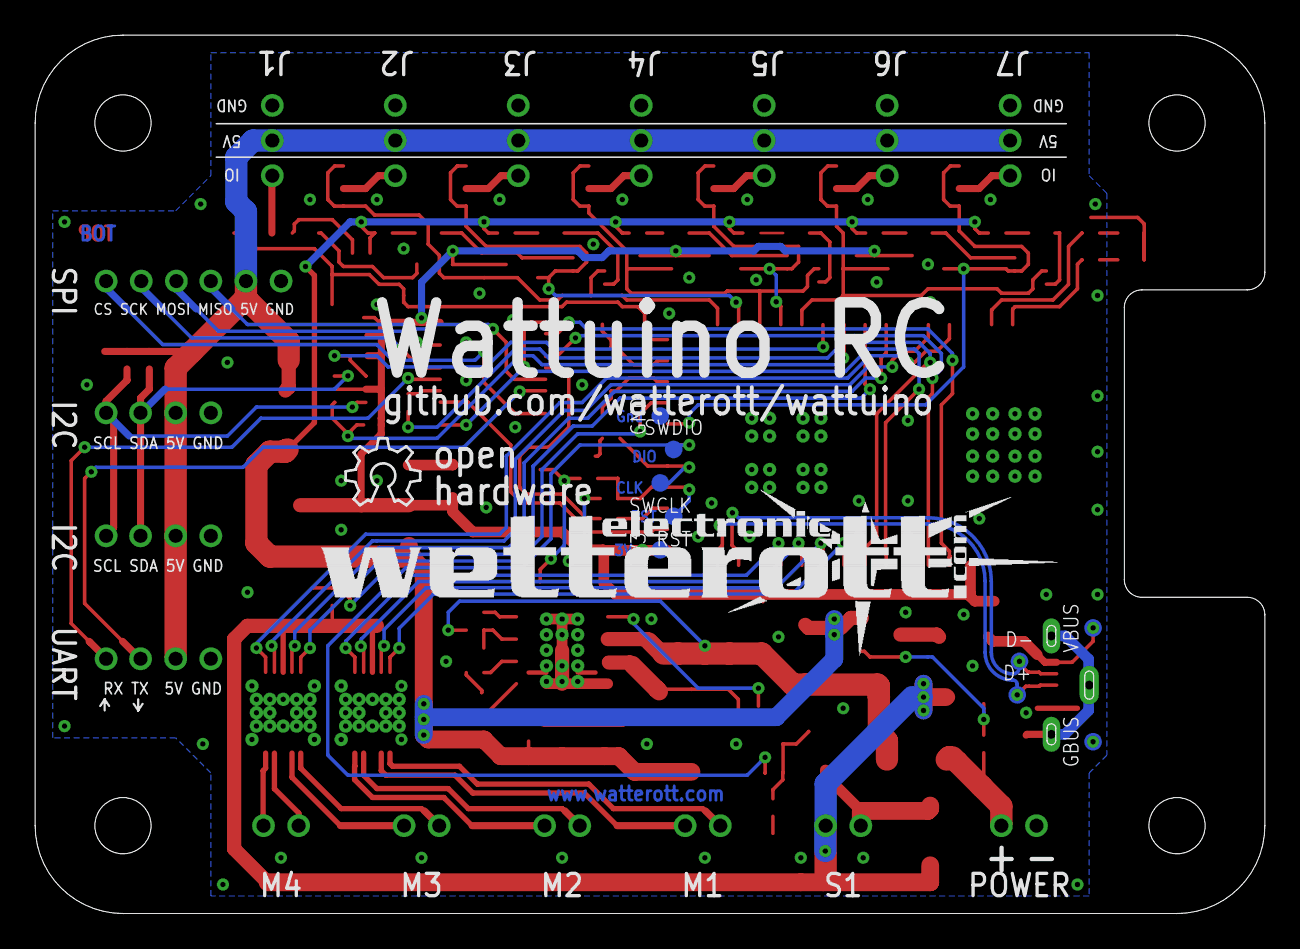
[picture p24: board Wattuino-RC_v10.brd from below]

Board: 2 copper layers, 70.0 x 50.0 mm, 144 parts (11 on the bottom side), 97 nets.

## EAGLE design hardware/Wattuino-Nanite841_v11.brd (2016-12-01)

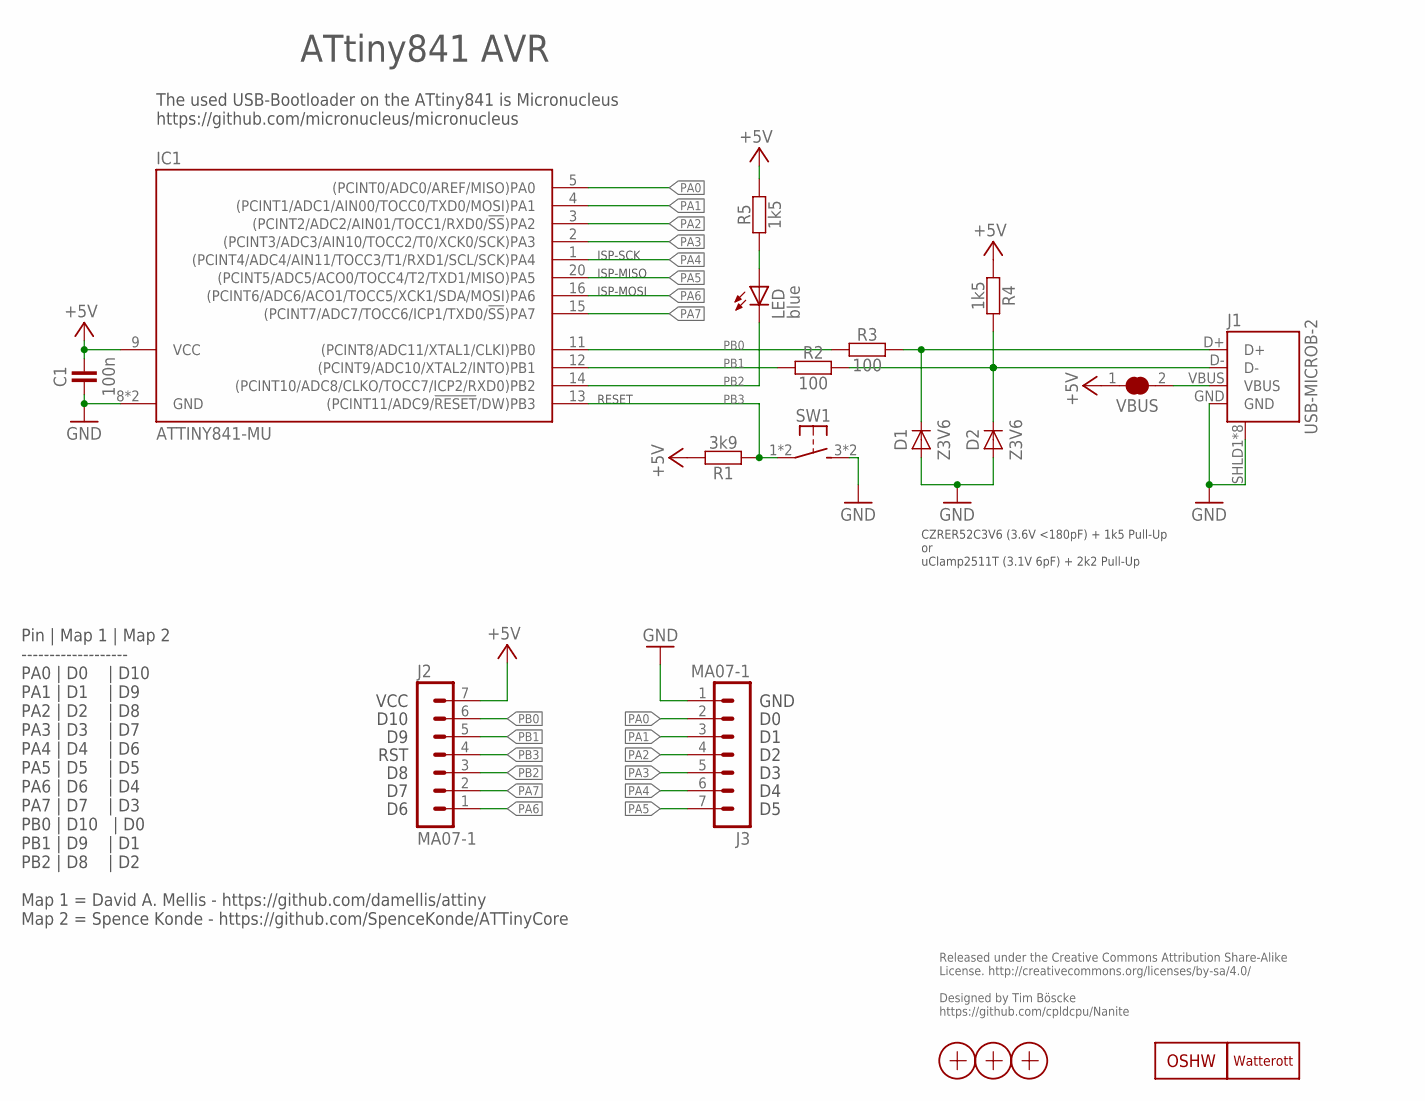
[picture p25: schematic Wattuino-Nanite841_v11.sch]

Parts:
C1: 100n; C0402
D1, D2: Z3V6; SOD882
IC1: ATTINY841-MU; QFN20-PAD
J1: USB-MICROB-2; USB-MICROB-10118194
J2, J3: MA07-1
LED: blue; C0603
LOGO1: LOGO-S_PLACE_S; SPARK_TPLACE_S
LOGO2: OSHW_LOGOX0070; OSHW_6X70
R1: 3k9; C0402
R2, R3: 100; C0402
R4, R5: 1k5; C0402
SW1: SW-TACTILE-PTS840P; PTS840P
VBUS: JUMPER2-0603-NC; JUMPER2-0603_NC
X1, X2, X3: PASSER-07; PASSER_07MM

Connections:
+5V: C1.2, IC1.9 (VCC), J2.7, R1.2, R4.1, R5.2, VBUS.1
D_N: D2.C, J1.D-, R2.2, R4.2
D_P: D1.C, J1.D+, R3.2
GND: C1.1, D1.A, D2.A, IC1.8 (GND), IC1.TP (GND), J1.GND, J1.SHLD1 (SHIELD), J1.SHLD2 (SHIELD), J1.SHLD3 (SHIELD), J1.SHLD4 (SHIELD), J1.SHLD5 (SHIELD), J1.SHLD6 (SHIELD), J1.SHLD7 (SHIELD), J1.SHLD8 (SHIELD), J3.1, SW1.3 (S1), SW1.4 (S1)
LED+: LED.A, R5.1
PA0: IC1.5 ((PCINT0/ADC0/AREF/MISO)PA0), J3.2
PA1: IC1.4 ((PCINT1/ADC1/AIN00/TOCC0/TXD0/MOSI)PA1), J3.3
PA2: IC1.3 ((PCINT2/ADC2/AIN01/TOCC1/RXD0/!SS!)PA2), J3.4
PA3: IC1.2 ((PCINT3/ADC3/AIN10/TOCC2/T0/XCK0/SCK)PA3), J3.5
PA4: IC1.1 ((PCINT4/ADC4/AIN11/TOCC3/T1/RXD1/SCL/SC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), J3.6
PA5: IC1.20 ((PCINT5/ADC5/ACO0/TOCC4/T2/TXD1/MISO)PA5), J3.7
PA6: IC1.16 ((PCINT6/ADC6/ACO1/TOCC5/XCK1/SDA/MOSI)P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), J2.1
PA7: IC1.15 ((PCINT7/ADC7/TOCC6/ICP1/TXD0/!SS!)PA7), J2.2
PB0: IC1.11 ((PCINT8/ADC11/XTAL1/CLKI)PB0), J2.6, R3.1
PB1: IC1.12 ((PCINT9/ADC10/XTAL2/INTO)PB1), J2.5, R2.1
PB2: IC1.14 ((PCINT10/ADC8/CLKO/TOCC7/ICP2/RXD0)PB2), J2.3, LED.C
PB3: IC1.13 ((PCINT11/ADC9/!RESET!/DW)PB3), J2.4, R1.1, SW1.1, SW1.2 (P1)
VBUS: J1.VBUS, VBUS.2

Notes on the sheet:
Released under the Creative Commons Attribution Share-Alike License. http://creativecommons.org/licenses/by-sa/4.0/ Designed by Tim Böscke https://github.com/cpldcpu/Nanite
The used USB-Bootloader on the ATtiny841 is Micronucleus https://github.com/micronucleus/micronucleus
CZRER52C3V6 (3.6V <180pF) + 1k5 Pull-Up or uClamp2511T (3.1V 6pF) + 2k2 Pull-Up
ATtiny841 AVR
GND
VCC
D10
RST
RESET
Pin | Map 1 | Map 2 ------------------- PA0 | D0 | D10 PA1 | D1 | D9 PA2 | D2 | D8 PA3 | D3 | D7 PA4 | D4 | D6 PA5 | D5 | D5 PA6 | D6 | D4 PA7 | D7 | D3 PB0 | D10 | D0 PB1 | D9 | D1 PB2 | D8 | D2 Map 1 = David A. Mellis - https://github.com/damellis/attiny Map 2 = Spence Konde - https://github.com/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
ISP-MOSI
ISP-MISO
ISP-SCK

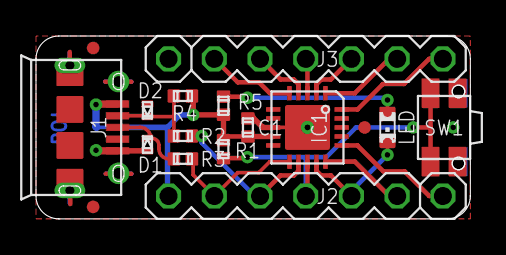
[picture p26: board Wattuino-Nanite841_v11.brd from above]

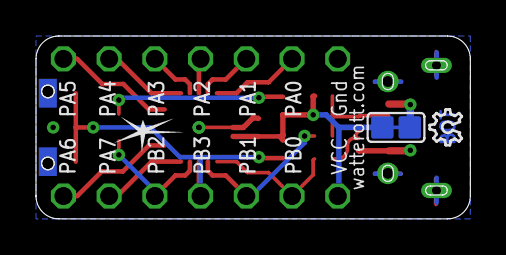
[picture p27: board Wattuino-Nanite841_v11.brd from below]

Board: 2 copper layers, 24.1 x 10.2 mm, 20 parts (3 on the bottom side), 18 nets.

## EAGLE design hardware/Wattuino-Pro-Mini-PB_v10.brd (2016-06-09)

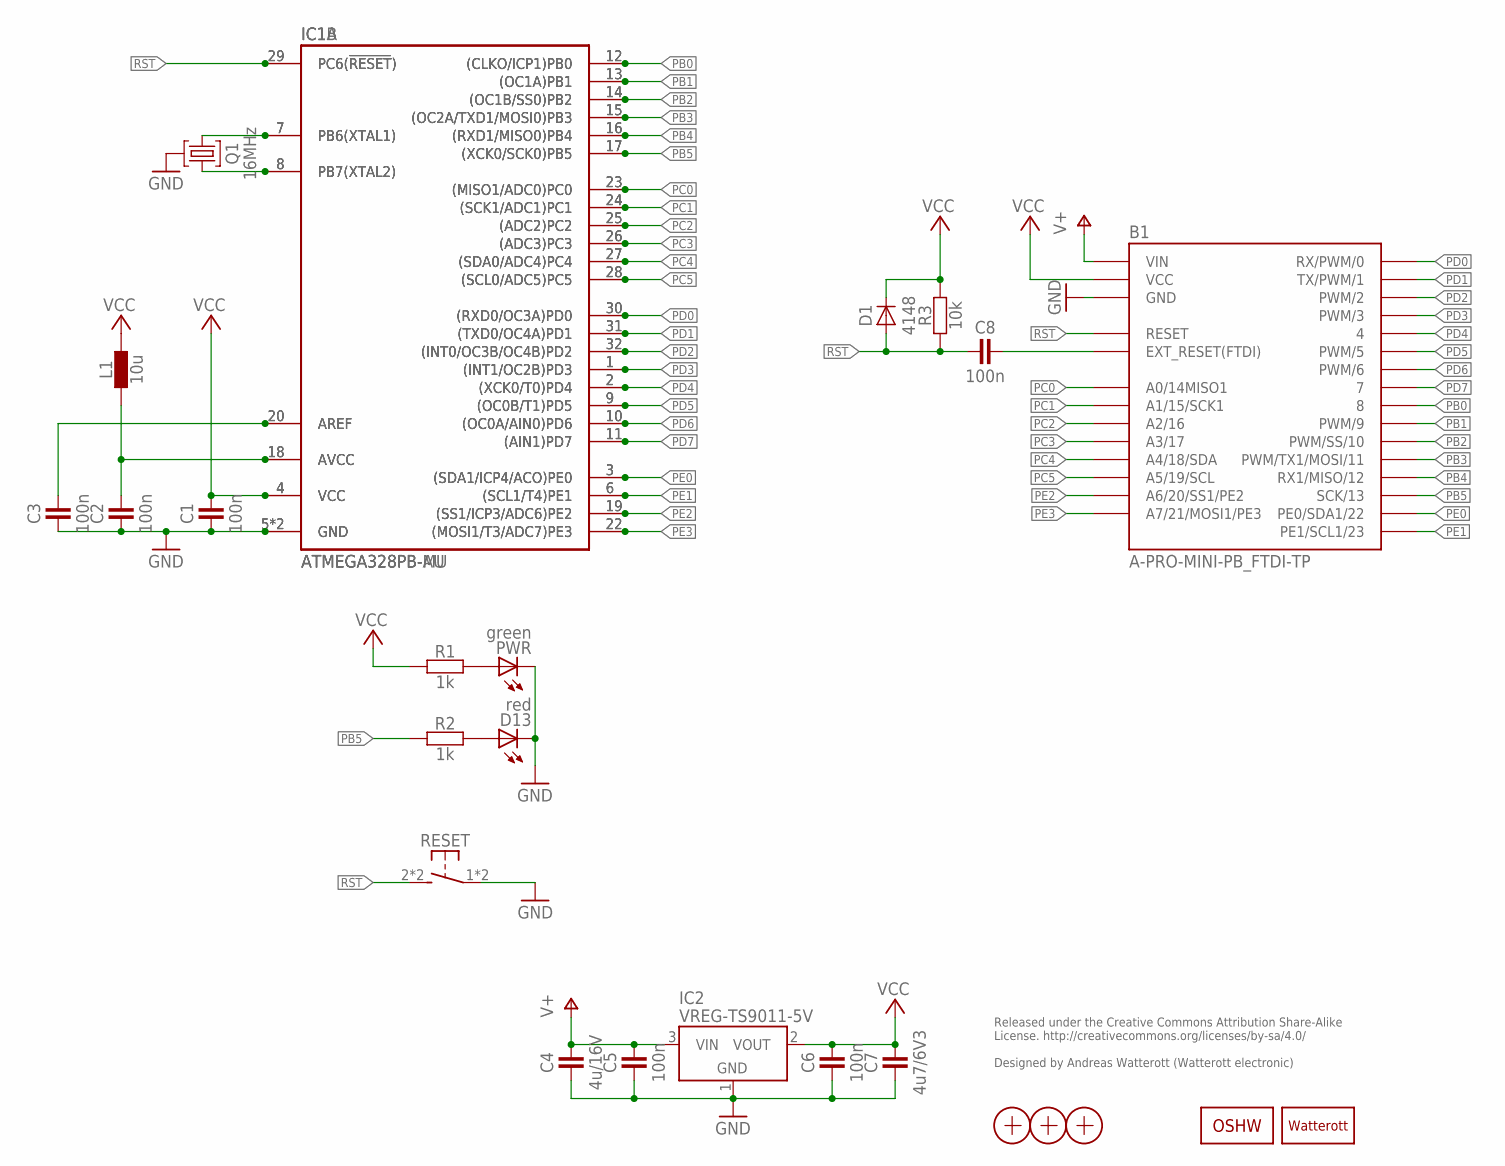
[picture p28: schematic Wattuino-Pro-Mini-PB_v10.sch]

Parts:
B1: A-PRO-MINI-PB_FTDI-TP; A-PRO-MINI-PB-FTDI_TP
C1, C2, C3, C5, C6, C8: 100n; C0402
C4: 4u/16V; C0805
C7: 4u7/6V3; C0402
D1: 4148; SOD882
D13: red; C0603
IC1A: ATMEGA328PB-AU; TQFP32
IC1B: ATMEGA328PB-MU; QFN32-PAD
IC2: VREG-TS9011-5V; SOT23
L1: 10u; C0603
LOGO1: OSHW_LOGOX0070; OSHW_6X70
LOGO2: LOGO-S_PLACE_S; SPARK_TPLACE_S
PWR: green; C0603
Q1: 16MHz; CRYSTAL_32X13
R1, R2: 1k; C0402
R3: 10k; C0402
RESET: SW-TACTILE-TL3315; TL3315N
X1, X2, X3: PASSER-07; PASSER_07MM

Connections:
AREF: C3.2, IC1A.20 (AREF), IC1B.20 (AREF)
AVCC: C2.2, IC1A.18 (AVCC), IC1B.18 (AVCC), L1.1
GND: B1.GND@1 (GND), B1.GND@2 (GND), B1.GND@3 (GND), B1.GND@4 (GND), C1.1, C2.1, C3.1, C4.1, C5.1, C6.1, C7.1, D13.C, IC1A.5 (GND), IC1A.21 (GND), IC1B.5 (GND), IC1B.21 (GND), IC2.1 (GND), PWR.C, Q1.GND, RESET.1, RESET.4 (P1)
unnamed: IC1A.8 (PB7(XTAL2)), IC1B.8 (PB7(XTAL2)), Q1.1
unnamed: IC1A.7 (PB6(XTAL1)), IC1B.7 (PB6(XTAL1)), Q1.2
unnamed: PWR.A, R1.2
unnamed: D13.A, R2.2
unnamed: B1.EXT_RST (EXT_RESET(FTDI)), C8.2
PB0: B1.8, IC1A.12 ((CLKO/ICP1)PB0), IC1B.12 ((CLKO/ICP1)PB0)
PB1: B1.9 (PWM/9), IC1A.13 ((OC1A)PB1), IC1B.13 ((OC1A)PB1)
PB2: B1.10 (PWM/SS/10), IC1A.14 ((OC1B/SS0)PB2), IC1B.14 ((OC1B/SS0)PB2)
PB3: B1.11 (PWM/TX1/MOSI/11), IC1A.15 ((OC2A/TXD1/MOSI0)PB3), IC1B.15 ((OC2A/TXD1/MOSI0)PB3)
PB4: B1.12 (RX1/MISO/12), IC1A.16 ((RXD1/MISO0)PB4), IC1B.16 ((RXD1/MISO0)PB4)
PB5: B1.13 (SCK/13), IC1A.17 ((XCK0/SCK0)PB5), IC1B.17 ((XCK0/SCK0)PB5), R2.1
PC0: B1.A0 (A0/14MISO1), IC1A.23 ((MISO1/ADC0)PC0), IC1B.23 ((MISO1/ADC0)PC0)
PC1: B1.A1 (A1/15/SCK1), IC1A.24 ((SCK1/ADC1)PC1), IC1B.24 ((SCK1/ADC1)PC1)
PC2: B1.A2 (A2/16), IC1A.25 ((ADC2)PC2), IC1B.25 ((ADC2)PC2)
PC3: B1.A3 (A3/17), IC1A.26 ((ADC3)PC3), IC1B.26 ((ADC3)PC3)
PC4: B1.A4 (A4/18/SDA), IC1A.27 ((SDA0/ADC4)PC4), IC1B.27 ((SDA0/ADC4)PC4)
PC5: B1.A5 (A5/19/SCL), IC1A.28 ((SCL0/ADC5)PC5), IC1B.28 ((SCL0/ADC5)PC5)
PD0: B1.RXD@1 (RX/PWM/0), B1.RXD@2 (RX/PWM/0), IC1A.30 ((RXD0/OC3A)PD0), IC1B.30 ((RXD0/OC3A)PD0)
PD1: B1.TXD@1 (TX/PWM/1), B1.TXD@2 (TX/PWM/1), IC1A.31 ((TXD0/OC4A)PD1), IC1B.31 ((TXD0/OC4A)PD1)
PD2: B1.2 (PWM/2), IC1A.32 ((INT0/OC3B/OC4B)PD2), IC1B.32 ((INT0/OC3B/OC4B)PD2)
PD3: B1.3 (PWM/3), IC1A.1 ((INT1/OC2B)PD3), IC1B.1 ((INT1/OC2B)PD3)
PD4: B1.4, IC1A.2 ((XCK0/T0)PD4), IC1B.2 ((XCK0/T0)PD4)
PD5: B1.5 (PWM/5), IC1A.9 ((OC0B/T1)PD5), IC1B.9 ((OC0B/T1)PD5)
PD6: B1.6 (PWM/6), IC1A.10 ((OC0A/AIN0)PD6), IC1B.10 ((OC0A/AIN0)PD6)
PD7: B1.7, IC1A.11 ((AIN1)PD7), IC1B.11 ((AIN1)PD7)
PE0: B1.PE0 (PE0/SDA1/22), IC1A.3 ((SDA1/ICP4/ACO)PE0), IC1B.3 ((SDA1/ICP4/ACO)PE0)
PE1: B1.PE1 (PE1/SCL1/23), IC1A.6 ((SCL1/T4)PE1), IC1B.6 ((SCL1/T4)PE1)
PE2: B1.A6 (A6/20/SS1/PE2), IC1A.19 ((SS1/ICP3/ADC6)PE2), IC1B.19 ((SS1/ICP3/ADC6)PE2)
PE3: B1.A7 (A7/21/MOSI1/PE3), IC1A.22 ((MOSI1/T3/ADC7)PE3), IC1B.22 ((MOSI1/T3/ADC7)PE3)
RST: B1.RST@1 (RESET), B1.RST@2 (RESET), C8.1, D1.A, IC1A.29 (PC6(!RESET!)), IC1B.29 (PC6(!RESET!)), R3.1, RESET.2 (S1), RESET.3 (S1)
V+: B1.VIN, C4.2, C5.2, IC2.3 (VIN)
VCC: B1.VCC@1 (VCC), B1.VCC@2 (VCC), C1.2, C6.2, C7.2, D1.C, IC1A.4 (VCC), IC1B.4 (VCC), IC2.2 (VOUT), L1.2, R1.1, R3.2

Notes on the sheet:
Released under the Creative Commons Attribution Share-Alike License. http://creativecommons.org/licenses/by-sa/4.0/ Designed by Andreas Watterott (Watterott electronic)

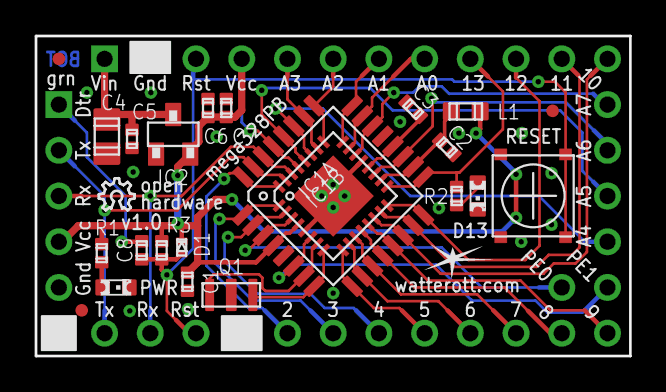
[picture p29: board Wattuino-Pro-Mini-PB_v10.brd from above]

Board: 2 copper layers, 33.0 x 17.8 mm, 26 parts (0 on the bottom side), 35 nets.

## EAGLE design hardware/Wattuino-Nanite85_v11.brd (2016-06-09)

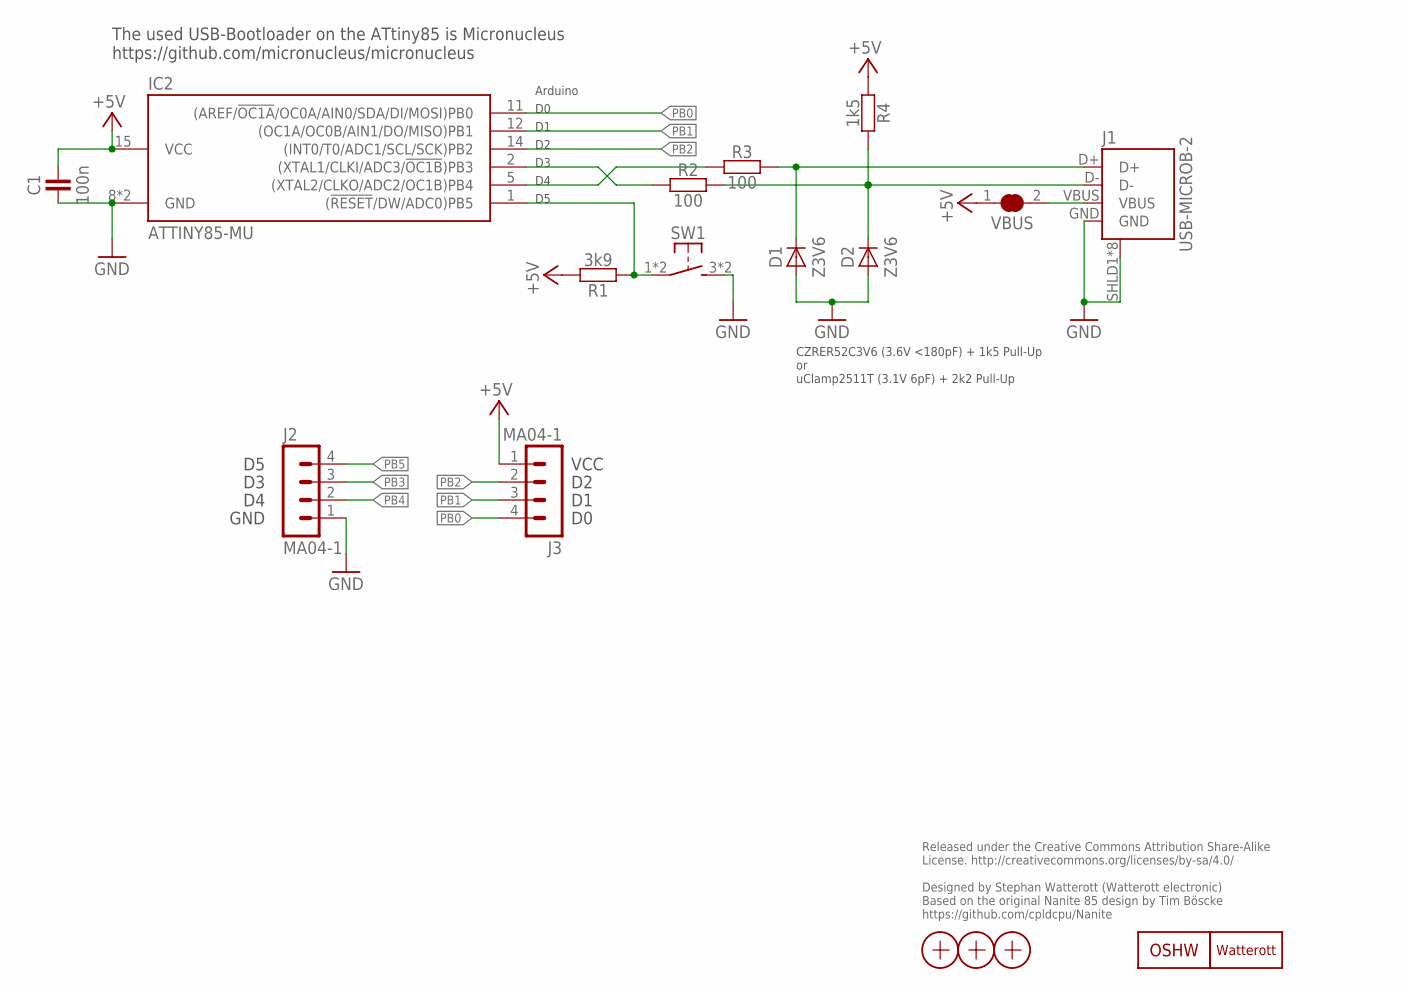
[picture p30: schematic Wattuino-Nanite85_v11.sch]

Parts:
C1: 100n; C0402
D1, D2: Z3V6; SOD882
IC2: ATTINY85-MU; QFN20-PAD
J1: USB-MICROB-2; USB-MICROB-10118194
J2, J3: MA04-1
LOGO1: LOGO-S_PLACE_S; SPARK_TPLACE_S
LOGO2: OSHW_LOGOX0070; OSHW_6X70
R1: 3k9; C0402
R2, R3: 100; C0402
R4: 1k5; C0402
SW1: SW-TACTILE-PTS840P; PTS840P
VBUS: JUMPER2-0603-NC; JUMPER2-0603_NC
X1, X2, X3: PASSER-07; PASSER_07MM

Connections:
+5V: C1.2, IC2.15 (VCC), J3.1, R1.2, R4.1, VBUS.1
D_N: D2.C, J1.D-, R2.2, R4.2
D_P: D1.C, J1.D+, R3.2
GND: C1.1, D1.A, D2.A, IC2.8 (GND), IC2.TP (GND), J1.GND, J1.SHLD1 (SHIELD), J1.SHLD2 (SHIELD), J1.SHLD3 (SHIELD), J1.SHLD4 (SHIELD), J1.SHLD5 (SHIELD), J1.SHLD6 (SHIELD), J1.SHLD7 (SHIELD), J1.SHLD8 (SHIELD), J2.1, SW1.3 (S1), SW1.4 (S1)
PB0: IC2.11 ((AREF/!OC1A!/OC0A/AIN0/SDA/DI/MOSI)PB0), J3.4
PB1: IC2.12 ((OC1A/OC0B/AIN1/DO/MISO)PB1), J3.3
PB2: IC2.14 ((INT0/T0/ADC1/SCL/SCK)PB2), J3.2
PB3: IC2.2 ((XTAL1/CLKI/ADC3/!OC1B!)PB3), J2.3, R2.1
PB4: IC2.5 ((XTAL2/CLKO/ADC2/OC1B)PB4), J2.2, R3.1
PB5: IC2.1 ((!RESET!/DW/ADC0)PB5), J2.4, R1.1, SW1.1, SW1.2 (P1)
VBUS: J1.VBUS, VBUS.2

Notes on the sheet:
Released under the Creative Commons Attribution Share-Alike License. http://creativecommons.org/licenses/by-sa/4.0/ Designed by Stephan Watterott (Watterott electronic) Based on the original Nanite 85 design by Tim Böscke https://github.com/cpldcpu/Nanite
The used USB-Bootloader on the ATtiny85 is Micronucleus https://github.com/micronucleus/micronucleus
CZRER52C3V6 (3.6V <180pF) + 1k5 Pull-Up or uClamp2511T (3.1V 6pF) + 2k2 Pull-Up
Arduino
GND
VCC

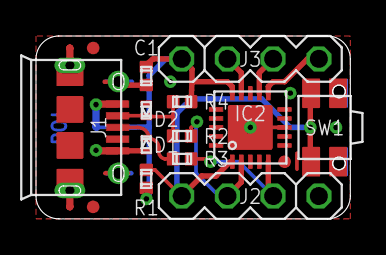
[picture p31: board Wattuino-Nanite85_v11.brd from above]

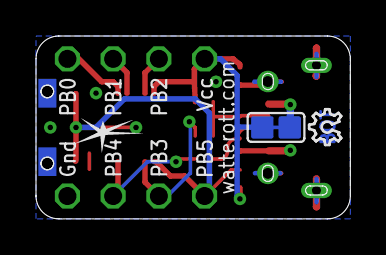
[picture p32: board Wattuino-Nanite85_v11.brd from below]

Board: 2 copper layers, 17.5 x 10.2 mm, 18 parts (3 on the bottom side), 11 nets.

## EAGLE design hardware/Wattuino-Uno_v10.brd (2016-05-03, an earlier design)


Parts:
ARD1: A-UNO_ISP-BRD; A-UNO-ISP
C1, C2, C3, C4, C5, C6, C9, C10, C11, C12, C17: 100n; C0402
C7, C8: 47p; C0402
C13, C14, C15, C16: 4u; C0603
C18, C19, C20: 10u; C1206
D1: 1N4148; SOD110
D2: D_SCHOTTKY-SS14; SMA_DO214AC
F1: 500mA; C0805
IC1: ATMEGA328-PU; DIL28
IC2: FT231XQ; QFN20-PAD
IC3: LDO-TS1117CW-5V; SOT223
IC4: LDO-TS9011-3V3; SOT23
J1: DC-JACK
J2: USB-B-H
J3: USB-MICRO; USB-MICRO-10103594
J-I2C: JST_PH_4B4B-PH-SM4-TB; JST_B4B-PH-SM4-TB
L: blue; C0603
L1: 10u; C0603
LOGO1: LOGO-S_PLACE_M; SPARK_TPLACE_M
LOGO2: OSHW_LOGOX0100; OSHW_6X100
PWR: green; C0603
Q1: 16MHz; CRYSTAL_32X13
R1, R10, R12: 10k; C0402
R2, R3, R6, R7, R8, R9: 1k; C0402
R4, R5: 27; C0402
R11: 0; C0402
RST1: SW-TACTILE-PTS840P; SW_PTS840P
RST2: SW-TACTILE-TL3315; SW_TL3315N
RST-EN: JUMPER2-0603
RX: red; C0603
T2: MOSFET-P-SOT23; SOT23
T3: MOSFET-N-SOT23; SOT23
TX: red; C0603
X1, X2, X3, X4: PASSER-07; PASSER_07MM

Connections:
3V3OUT: C6.2, IC2.10 (3V3OUT), IC2.11 (!RESET), IC2.20 (VCCIO)
+3V3: ARD1.3V3, C12.2, C16.2, IC4.2 (VO), R6.2, R7.2, R8.2, R9.2
+5V: ARD1.5V, ARD1.IOREF, ARD1.VCC (5V), C2.2, C5.2, C10.2, C11.2, C14.2, C15.2, C20.2, D1.C, IC1.7 (VCC), IC2.12 (VCC), IC3.2 (VO), IC3.4 (VO), IC4.3 (VI), J-I2C.2, L1.1, R1.2, T2.2 (S)
AD0: ARD1.A0 (AIN0), IC1.23 ((ADC0)PC0)
AD1: ARD1.A1 (AIN1), IC1.24 ((ADC1)PC1)
AD2: ARD1.A2 (AIN2), IC1.25 ((ADC2)PC2)
AD3: ARD1.A3 (AIN3), IC1.26 ((ADC3)PC3)
AD4/SDA: ARD1.A4 (AIN4/SDA), ARD1.SDA, IC1.27 ((SDA/ADC4)PC4), J-I2C.3
AD5/SCL: ARD1.A5 (AIN5/SCL), ARD1.SCL, IC1.28 ((SCL/ADC5)PC5), J-I2C.4
AREF: ARD1.AREF, C4.2, IC1.21 (AREF)
AVCC: C3.2, IC1.20 (AVCC), L1.2
D0/RX: ARD1.0 (RX/0), IC1.2 ((RXD)PD0), R2.2
D1/TX: ARD1.1 (TX/1), IC1.3 ((TXD)PD1), R3.2
D2: ARD1.2, IC1.4 ((INT0)PD2)
D3: ARD1.3 (PWM/3), IC1.5 ((OC2B/INT1)PD3)
D4: ARD1.4, IC1.6 ((XCK/T0)PD4)
D5: ARD1.5 (PWM/5), IC1.11 ((OC0B/T1)PD5)
D6: ARD1.6 (PWM/6), IC1.12 ((OC0A/AIN0)PD6)
D7: ARD1.7, IC1.13 ((AIN1)PD7)
D8: ARD1.8, IC1.14 ((CLKO/ICP1)PB0)
D9: ARD1.9 (PWM/9), IC1.15 ((OC1A)PB1)
D10: ARD1.10 (PWM/SS/10), IC1.16 ((SS/OC1B)PB2)
D11: ARD1.11 (PWM/MOSI/11), ARD1.MOSI, IC1.17 ((OC2A/MOSI)PB3)
D12: ARD1.12 (MISO/12), ARD1.MISO, IC1.18 ((MISO)PB4)
D13: ARD1.13 (SCK/13), ARD1.SCK, IC1.19 ((SCK)PB5), T3.1 (G)
DN: IC2.9 (USBDM), R5.2
DP: IC2.8 (USBDP), R4.2
DTR: C1.2, RST-EN.2
DTR_FT: IC2.18 (!DTR), RST-EN.1
D_N: C7.2, J2.D-, J3.D-, R5.1
D_P: C8.2, J2.D+, J3.D+, R4.1
GND: ARD1.GND@1 (GND), ARD1.GND@2 (GND), ARD1.GND@3 (GND), ARD1.GND@4 (GND), C2.1, C3.1, C4.1, C5.1, C6.1, C7.1, C8.1, C9.1, C10.1, C11.1, C12.1, C13.1, C14.1, C15.1, C16.1, C17.1, C18.1, C19.1, C20.1, IC1.8 (GND), IC1.22 (GND), IC2.3 (GND), IC2.13 (GND), IC2.TP (GND), IC3.1 (GND), IC4.1 (GND), J1.1, J1.2, J2.GND, J3.GND, J-I2C.1, PWR.C, Q1.GND, R10.1, R11.2, RST1.3 (S1), RST1.4 (S2), RST2.2 (S1), RST2.3 (S2), T3.2 (S)
unnamed: PWR.A, R9.1
unnamed: L.C, T3.3 (D)
unnamed: L.A, R6.1
unnamed: R7.1, TX.A
unnamed: R8.1, RX.A
RST: ARD1.RST (RESET), ARD1.RST2 (RESET), C1.1, D1.A, IC1.1 (PC6(!RESET!)), R1.1, RST1.1, RST1.2, RST2.1, RST2.4 (P2)
RXLED: IC2.14 (CBUS1), RX.C
RX_FT: IC2.1 (RXD), R3.1
SHLD: J2.SHLD1 (SHIELD), J2.SHLD2 (SHIELD), J3.SHLD1 (SHIELD), J3.SHLD2 (SHIELD), R11.1
TXLED: IC2.7 (CBUS2), TX.C
TX_FT: IC2.17 (TXD), R2.1
USBVCC: F1.2, T2.3 (D)
VBUS: C17.2, F1.1, J2.VBUS, J3.VBUS
VEXT: D2.A, J1.3, R12.1
VEXT2: R10.2, R12.2, T2.1 (G)
VIN: ARD1.VIN, C9.2, C13.2, C18.2, C19.2, D2.C, IC3.3 (VI)
XTAL1: IC1.9 (PB6(XTAL1)), Q1.2
XTAL2: IC1.10 (PB7(XTAL2)), Q1.1

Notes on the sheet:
Released under the Creative Commons Attribution Share-Alike License. http://creativecommons.org/licenses/by-sa/4.0/ Designed by Andreas Watterott (Watterott electronic) Inspired by the original Arduino Uno design - http://arduino.cc
ATmega328
FT231X
USB
Power Supply


Board: 2 copper layers, 68.6 x 53.3 mm, 61 parts (0 on the bottom side), 50 nets.

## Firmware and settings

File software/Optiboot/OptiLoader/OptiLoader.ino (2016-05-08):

// optiLoader.ino
//
// this sketch allows an Arduino to program Optiboot onto any other
// Arduino-like device containing ATmega8, ATmega168, or ATmega328
// microcontroller chips.
//
// Copyright (c) 2011, 2015 by Bill Westfield ("WestfW")

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
//
// this sketch allows an Arduino to program Optiboot onto any other
// Arduino-like device containing ATmega8, ATmega168, or ATmega328
// microcontroller chips.
//
// It is based on AVRISP
//
// Designed to connect to a generic programming cable,
// using the following pins:
// 10: slave reset
// 11: MOSI
// 12: MISO
// 13: SCK
//  9: Power to external chip.
//     This is a little questionable, since the power it is legal to draw
//     from a PIC pin is pretty close to the power consumption of an AVR
//     chip being programmed.  But it permits the target to be entirely
//     powered down for safe reconnection of the programmer to additional
//     targets, and it seems to work for most Arduinos.  If the target board
//     contains additional circuitry and is expected to draw more than 40mA,
//     connect the target power to a stronger source of +5V.  Do not use pin
//     9 to power more complex Arduino boards that draw more than 40mA, such
//     as the Arduino Uno Ethernet !
//
// If the aim is to reprogram the bootloader in one Arduino using another
// Arudino as the programmer, you can just use jumpers between the connectors
// on the Arduino board.  In this case, connect:
// Pin 13 to Pin 13
// Pin 12 to Pin 12
// Pin 11 to Pin 11
// Pin 10 (of "programmer") to RESET (of "target" (on the "power" connector))
// +5V to +5V and GND to GND.  Only the "programmer" board should be powered
//     by USB or external power.
//
// ----------------------------------------------------------------------

// The following credits are from AVRISP.  It turns out that there isn't
// a lot of AVRISP left in this sketch, but probably if AVRISP had never
// existed,  this sketch would not have been written.
//
// October 2009 by David A. Mellis
// - Added support for the read signature command
// 
// February 2009 by Randall Bohn
// - Added support for writing to EEPROM (what took so long?)
// Windows users should consider WinAVR's avrdude instead of the
// avrdude included with Arduino software.
//
// January 2008 by Randall Bohn
// - Thanks to Amplificar for helping me with the STK500 protocol
// - The AVRISP/STK500 (mk I) protocol is used in the arduino bootloader
// - The SPI functions herein were developed for the AVR910_ARD programmer 
// - More information at http://code.google.com/p/mega-isp


#include <avr/pgmspace.h>
#include "optiLoader.h"

char Arduino_preprocessor_hint;

// Pins to target
#define SCK     13
#define MISO    12
#define MOSI    11
#define RESET   10
#define POWER    9 // inverted for P-Chn MosFet
#define LED      8
#define SWITCH   7 // switch to start programming

#define SPI_SPEED_SLOW ((1<<SPR1)|(1<<SPR0)) // 125kHz clk=Fcpu/128
#define SPI_SPEED_FAST ((0<<SPR1)|(1<<SPR0)) // 1MHz   clk=Fcpu/16
#define SPI_SPEED_MASK ((1<<SPR1)|(1<<SPR0))

// STK Definitions; we can still use these as return codes
#define STK_OK 0x10
#define STK_FAILED 0x11

// Useful message printing definitions
#define fp(string) flashprint(PSTR(string));
#define debug(string) // flashprint(PSTR(string));
#define error(string) flashprint(PSTR(string)); perror=1;

// Forward references
void pulse(int pin, int times);
void read_image(const image_t *ip);

// Global Variables
extern const image_t PROGMEM image_328p, image_328pb;

const image_t * images[] = //Table of defined images
{
  &image_328p , &image_328pb, 0
};

/*
 * Table of "Aliases."  Chips that are effectively the same as chips
 * that we have a bootloader for.  These work by simply overriding the
 * signature read with the signature of the chip we "know."
 */
const alias_t aliases[] =
{
  { "atmega328",   0x9514, 0x950F }  /* Treat 328 same as 328P */
  //{ "atmega328p",  0x950F, 0x9514 },  /* Treat 328P same as 328 */
  //{ "atmega328pb", 0x9516, 0x9514 },  /* Treat 328PB same as 328 */
};

int pmode=0;
int perror=0;
// address for reading and writing, set by 'U' command
int here;

uint16_t target_type = 0;   /* type of target_cpu */
uint16_t target_startaddr;
uint8_t target_pagesize;       /* Page size for flash programming (bytes) */
uint8_t *buff;

const image_t *target_flashptr;          /* pointer to target info in flash */
uint8_t target_code[512];        /* The whole code */

void setup (void) {
  end_pmode();
  pinMode(LED, OUTPUT);       /* set LED pin as output */
  digitalWrite(LED, LOW);     /* LED off */
  pinMode(SWITCH, INPUT);     /* set SWITCH pin as input */
  digitalWrite(SWITCH, HIGH); /* SWITCH pull-up on */

  Serial.begin(115200);       /* Initialize serial for status msgs */
  fp("\nOptiLoader Bootstrap Programmer (" __DATE__ ")\n\n");
}

void loop (void) {
  pulse(LED, 3);
  if (target_poweron()) {   /* Turn on target power */
    perror = 0;
    do {
      if (!target_identify())     /* Figure out what kind of CPU */
        break;
      if (!target_findimage())    /* look for an image */
        break;
      if (!target_progfuses())    /* get fuses ready to program */
        break;
      //SPI speed up after fuse programming
      SPCR = (SPCR & ~SPI_SPEED_MASK) | SPI_SPEED_FAST;
      if (!target_program())      /* Program the image */
        break;
      (void) target_normfuses();  /* reset fuses to normal mode */
    } 
    while (0);
  }
  else {
    Serial.println();
  }
  target_poweroff();      /* turn power off */

  if (perror == 0)
    digitalWrite(LED, HIGH);  /* LED on */
  else
    digitalWrite(LED, LOW);   /* LED off */

  while(Serial.read() != -1); /* clear buffer */
  fp("\nType 'G' or hit RESET for next chip.\n")

#ifdef SWITCH
  int sw_state = digitalRead(SWITCH);
#endif
  while (1)
  {
    if (Serial.read() == 'G')
    {
      break;
    }
#ifdef SWITCH
    if(sw_state != digitalRead(SWITCH))
    {
      /*
      digitalWrite(LED, LOW);
      fp("\nWaiting for 2nd press...\n")
      delay(500);
      sw_state = digitalRead(SWITCH);
      while (sw_state == digitalRead(SWITCH));
      */
      break;
    }
#endif
    if (perror != 0)
    {
      pulse(LED, 3);
    }
  }
}

/*
 * Low level support functions
 */

/*
 * flashprint
 * print a text string direct from flash memory to Serial
 */
void flashprint (const char p[])
{
  uint8_t c;
  while (0 != (c = pgm_read_byte(p++))) {
    Serial.write(c);
  }
}

/*
 * hexton
 * Turn a Hex digit (0..9, A..F) into the equivalent binary value (0-16)
 */
uint8_t hexton (uint8_t h)
{
  if (h >= '0' && h <= '9')
    return(h - '0');
  if (h >= 'A' && h <= 'F')
    return((h - 'A') + 10);
  error("Bad hex digit!");
  return(0);
}

/*
 * pulse
 * turn a pin on and off a few times; indicates life via LED
 */
#define PTIME 40
void pulse (int pin, int times) {
  do {
    digitalWrite(pin, HIGH);
    delay(PTIME);
    digitalWrite(pin, LOW);
    delay(PTIME);
  } 
  while (times--);
}

/*
 * spi_wait
 * wait for SPI transfer to complete
 */
void spi_wait (void) {
  debug("spi_wait");
  do {
  } 
  while (!(SPSR & (1 << SPIF)));
}

/*
 * spi_send
 * send a byte via SPI, wait for the transfer.
 */
uint8_t spi_send (uint8_t b) {
  uint8_t reply;
  SPDR=b;
  spi_wait();
  reply = SPDR;
  return reply;
}

/*
 * Functions specific to ISP programming of an AVR
 */

unsigned long spi_transaction (uint8_t a, uint8_t b, uint8_t c, uint8_t d) {
  uint8_t n, m;
  spi_send(a); 
  n=spi_send(b);
  //if (n != a) error = -1;
  m=spi_send(c);
  return 0xFFFFFF & ((((uint32_t)n)<<16)+(m<<8) + spi_send(d));
}

void spi_poll_ready (void) {
  delay(5);
  do{
  }
  while((spi_transaction(0xF0, 0x00, 0x00, 0x00) & 0x1) != 0);
}

uint16_t start_pmode () {
  uint16_t result;
  uint8_t x;

  // initialize the AVR SPI peripheral
  pinMode(MISO, INPUT);
  pinMode(MOSI, OUTPUT);
  pinMode(SCK, OUTPUT);
  SPCR = (1<<SPE)|(1<<MSTR)|SPI_SPEED_SLOW;
  x=SPSR;
  x=SPDR;

  // following delays may not work on all targets...
  pinMode(RESET, OUTPUT);
  digitalWrite(RESET, HIGH);
  delay(20);
  digitalWrite(RESET, LOW);
  delay(20);
  debug("...spi_transaction");
  result = spi_transaction(0xAC, 0x53, 0x00, 0x00);
  debug("...Done");
  pmode = 1;
  return result;
}

void end_pmode (void) {
  SPCR = 0;                 /* reset SPI */
  digitalWrite(MISO, LOW);    /* Make sure pullups are off too */
  pinMode(MISO, INPUT);
  digitalWrite(MOSI, LOW);
  pinMode(MOSI, INPUT);
  digitalWrite(SCK, LOW);
  pinMode(SCK, INPUT);
  digitalWrite(RESET, LOW);
  pinMode(RESET, INPUT);
  pmode = 0;
}

/*
 * read_image
 *
 * Read an intel hex image from a string in pgm memory.
 * We assume that the image does not exceed the 512 bytes that we have
 * allowed for it to have.  that would be bad.
 * Also read other data from the image, such as fuse and protecttion byte
 * values during programming, and for after we're done.
 */
void read_image (const image_t *ip)
{
  uint16_t len, totlen=0, addr;
  const char *hextext = &ip->image_hexcode[0];
  target_startaddr = 0;
  target_pagesize = pgm_read_byte(&ip->image_pagesize);
  uint8_t b, cksum = 0;

  while (1) {
    if (pgm_read_byte(hextext++) != ':') {
      error("No colon");
      break;
    }
    len = hexton(pgm_read_byte(hextext++));
    len = (len<<4) + hexton(pgm_read_byte(hextext++));
    cksum = len;

    b = hexton(pgm_read_byte(hextext++)); /* record type */
    b = (b<<4) + hexton(pgm_read_byte(hextext++));
    cksum += b;
    addr = b;
    b = hexton(pgm_read_byte(hextext++)); /* record type */
    b = (b<<4) + hexton(pgm_read_byte(hextext++));
    cksum += b;
    addr = (addr << 8) + b;
    if (target_startaddr == 0) {
      target_startaddr = addr;
      fp("  Start address at ");
      Serial.println(addr, HEX);
    } 
    else if (addr == 0) {
      break;
    }

    b = hexton(pgm_read_byte(hextext++)); /* record type */
    b = (b<<4) + hexton(pgm_read_byte(hextext++));
    cksum += b;

    for (uint8_t i=0; i < len; i++) {
      b = hexton(pgm_read_byte(hextext++));
      b = (b<<4) + hexton(pgm_read_byte(hextext++));
      if (addr - target_startaddr >= sizeof(target_code)) {
        error("\nCode extends beyond allowed range");
        break;
      }
      target_code[addr++ - target_startaddr] = b;
      cksum += b;
#if VERBOSE
      Serial.print(b, HEX);
      Serial.write(' ');
#endif
      totlen++;
      if (totlen >= sizeof(target_code)) {
        error("\nToo much code");
        break;
      }
    }
    b = hexton(pgm_read_byte(hextext++)); /* checksum */
    b = (b<<4) + hexton(pgm_read_byte(hextext++));
    cksum += b;
    if (cksum != 0) {
      error("\nBad checksum: ");
      Serial.print(cksum, HEX);
    }
    if (pgm_read_byte(hextext++) != '\n') {
      error("\nNo end of line");
      break;
    }
#if VERBOSE
    Serial.println();
#endif
  }
  fp("  Total bytes read: ");
  Serial.println(totlen);
}

/*
 * target_findimage
 *
 * given target_type loaded with the relevant part of the device signature,
 * search the hex images that we have programmed in flash, looking for one
 * that matches.
 */
boolean target_findimage ()
{
  const image_t *ip;
  fp("Searching for image...\n");
  // Search through our table of chip aliases first
  for (uint8_t i=0; i < sizeof(aliases)/sizeof(aliases[0]); i++) {
    const alias_t *a = &aliases[i];
    if (a->real_chipsig == target_type) {
      fp("  Compatible bootloader for ");
      Serial.println(a->alias_chipname);
      target_type = a->alias_chipsig;  /* Overwrite chip signature */
      break;
    }
  }
  // Search through our table of self-contained images.
  for (uint8_t i=0; i < sizeof(images)/sizeof(images[0]); i++) {
    target_flashptr = ip = images[i];
    if (ip && (pgm_read_word(&ip->image_chipsig) == target_type)) {
      fp("  Found \"");
      flashprint(&ip->image_name[0]);
      fp("\" for ");
      flashprint(&ip->image_chipname[0]);
      fp("\n");
      read_image(ip);
      return true;
    }
  }
  fp(" Not Found\n");
  return(false);
}

/*
 * target_identify
 * read the signature bytes (if possible) and check whether it's
 * a legal value (atmega8, atmega168, atmega328)
 */
boolean target_identify ()
{
  boolean result;
  target_type = 0;
  fp("\nReading signature:");
  target_type = read_signature();
  if (target_type == 0 || target_type == 0xFFFF) {
    error(" Bad value: ");
    result = false;
  } 
  else {
    result = true;
  }
  Serial.println(target_type, HEX);
  if (target_type == 0) {
    fp("  (no target attached?)\n");
  }
  return result;
}

/*
 * target_progfuses
 * given initialized target image data, re-program the fuses to allow
 * the optiboot image to be programmed.
 */
boolean target_progfuses ()
{
  uint8_t f;

  fp("\nErase Chip");
  spi_transaction(0xAC, 0x80, 0, 0);  /* chip erase */
  delay(250);
  spi_poll_ready();

  fp("\nSetting fuses for programming");
  f = pgm_read_byte(&target_flashptr->image_progfuses[FUSE_PROT]);
  if (f) {
    fp("\n  Lock: ");
    Serial.print(f, HEX);
    fp(" ");
    Serial.print(spi_transaction(0xAC, 0xE0, 0x00, f), HEX);
    spi_poll_ready();
  }
  f = pgm_read_byte(&target_flashptr->image_progfuses[FUSE_LOW]);
  if (f) {
    fp("  Low: ");
    Serial.print(f, HEX);
    fp(" ");
    Serial.print(spi_transaction(0xAC, 0xA0, 0x00, f), HEX);
    spi_poll_ready();
  }
  f = pgm_read_byte(&target_flashptr->image_progfuses[FUSE_HIGH]);
  if (f) {
    fp("  High: ");
    Serial.print(f, HEX);
    fp(" ");
    Serial.print(spi_transaction(0xAC, 0xA8, 0x00, f), HEX);
    spi_poll_ready();
  }
  f = pgm_read_byte(&target_flashptr->image_progfuses[FUSE_EXT]);
  if (f) {
    fp("  Ext: ");
    Serial.print(f, HEX);
    fp(" ");
    Serial.print(spi_transaction(0xAC, 0xA4, 0x00, f), HEX);
    spi_poll_ready();
  }
  Serial.println();

  return true;
}

/*
 * target_program
 * Actually program the image into the target chip
 */
boolean target_program ()
{
  int l;        /* actual length */

  fp("\nProgramming bootloader: ");
  here = target_startaddr>>1;     /* word address */
  buff = target_code;
  l = 512;
  Serial.print(l, DEC);
  fp(" bytes at 0x");
  Serial.println(here, HEX);

  if (write_flash(l) != STK_OK) {
    error("\nFlash Write Failed");
    return false;
  }
  return true;
}

/*
 * target_normfuses
 * reprogram the fuses to the state they should be in for bootloader
 * based programming
 */
boolean target_normfuses ()
{
  uint8_t f;
  fp("\nRestoring normal fuses");

  f = pgm_read_byte(&target_flashptr->image_normfuses[FUSE_LOW]);
  if (f) {
    fp("  Low: ");
    Serial.print(f, HEX);
    fp(" ");
    Serial.print(spi_transaction(0xAC, 0xA0, 0x00, f), HEX);
    spi_poll_ready();
  }
  f = pgm_read_byte(&target_flashptr->image_normfuses[FUSE_HIGH]);
  if (f) {
    fp("  High: ");
    Serial.print(f, HEX);
    fp(" ");
    Serial.print(spi_transaction(0xAC, 0xA8, 0x00, f), HEX);
    spi_poll_ready();
  }
  f = pgm_read_byte(&target_flashptr->image_normfuses[FUSE_EXT]);
  if (f) {
    fp("  Ext: ");
    Serial.print(f, HEX);
    fp(" ");
    Serial.print(spi_transaction(0xAC, 0xA4, 0x00, f), HEX);
    spi_poll_ready();
  }
  f = pgm_read_byte(&target_flashptr->image_normfuses[FUSE_PROT]);
  if (f) {
    fp("\n  Lock: ");
    Serial.print(f, HEX);
    fp(" ");
    Serial.print(spi_transaction(0xAC, 0xE0, 0x00, f), HEX);
    spi_poll_ready();
  }
  Serial.println();
  return true;
}

/*
 * target_poweron
 * Turn on power to the target chip (assuming that it is powered through
 * the relevant IO pin of THIS arduino.)
 */
boolean target_poweron ()
{
  uint16_t result;

  fp("Target power ON! ...");
  digitalWrite(POWER, LOW);
  pinMode(POWER, OUTPUT);
  //digitalWrite(POWER, HIGH);
  delay(100);
  digitalWrite(RESET, LOW);  // reset it right away
  pinMode(RESET, OUTPUT);
  delay(5);
  // Check if the target is pulling RESET HIGH by reverting to input
  pinMode(RESET, INPUT);
  delay(1);
  if (digitalRead(RESET) != HIGH) {
    error("\nNo RESET pullup detected! - no target?");
    return false;
  }

  delay(100);
  fp("\nStarting Program Mode");
  result = start_pmode();
  if ((result & 0xFF00) != 0x5300) {
    error(" - Failed, result = 0x");
    Serial.println(result, HEX);
    return false;
  }
  fp(" [OK]\n");
  return true;
}

boolean target_poweroff ()
{
  end_pmode();
  digitalWrite(POWER, HIGH);
  //digitalWrite(POWER, LOW);
  //pinMode(POWER, INPUT);
  fp("\nTarget power OFF!\n");
  return true;
}

void flash (uint8_t hilo, int addr, uint8_t data) {
#if VERBOSE
  Serial.print(data, HEX);
  fp(":");
  Serial.print(spi_transaction(0x40+8*hilo, 
  addr>>8 & 0xFF, 
  addr & 0xFF,
  data), HEX);
  fp(" ");
#else
  (void) spi_transaction(0x40+8*hilo, 
  addr>>8 & 0xFF, 
  addr & 0xFF,
  data);
#endif
}

void commit (int addr) {
  fp("  Commit Page: ");
  Serial.print(addr, HEX);
  fp(":");
  Serial.println(spi_transaction(0x4C, (addr >> 8) & 0xFF, addr & 0xFF, 0), HEX);
  delay(100);
}

//#define _current_page(x) (here & 0xFFFFE0)
int current_page (int addr) {
  if (target_pagesize ==  32) return here & 0xFFFFFFF0;
  if (target_pagesize ==  64) return here & 0xFFFFFFE0;
  if (target_pagesize == 128) return here & 0xFFFFFFC0;
  return here;
}

uint8_t write_flash (int length) {
  if (target_pagesize < 1) return STK_FAILED;
  //if (target_pagesize != 64) return STK_FAILED;
  int page = current_page(here);
  int x = 0;
  while (x < length) {
    if (page != current_page(here)) {
      commit(page);
      page = current_page(here);
    }
    flash(LOW, here, buff[x]);
    flash(HIGH, here, buff[x+1]);
    x+=2;
    here++;
  }
  commit(page);
  return STK_OK;
}

uint16_t read_signature () {
  uint8_t sig_middle = spi_transaction(0x30, 0x00, 0x01, 0x00);
  uint8_t sig_low = spi_transaction(0x30, 0x00, 0x02, 0x00);
  return ((sig_middle << 8) + sig_low);
}

/*
 * Bootload images.
 * These are the intel Hex files produced by the optiboot makefile,
 * with a small amount of automatic editing to turn them into C strings,
 * and a header attched to identify them
 *
 * Emacs keyboard macro:

      4*SPC     ;; self-insert-command
      "     ;; self-insert-command
      C-e     ;; move-end-of-line
      \     ;; self-insert-command
      n"      ;; self-insert-command * 2
      C-n     ;; next-line
      C-a     ;; move-beginning-of-line

 */

const image_t PROGMEM image_328p = {
  { "optiboot_m328p.hex" },
  { "atmega328p" },
    0x950F,              /* 0x1E 0x95 0x0F Signature bytes for 328P */
  { 0xFF,0xFF,0xD6,0xFD },
  { 0xCF,0x00,0x00,0x00 },
    128,
  {
    ":107E00001F92CDB7DEB7112484B714BE982F9D7092\n"
    ":107E100009F0E6D082E08093C00088E18093C10041\n"
    ":107E200086E08093C20080E18093C4008EE0C3D0DE\n"
    ":107E300010928500109284004899FECF489BFECF97\n"
    ":107E400081E0809381004899FECF109281002091BB\n"
    ":107E50008400822F20918500922F089644E0969509\n"
    ":107E600087954A95E1F701978093C40098D08033B5\n"
    ":107E7000E9F7A7D0812C912C13E001E025E0F22E48\n"
    ":107E800031E1E32E8CD0813479F489D0898399D083\n"
    ":107E90008981823811F482E005C0813811F486E0CE\n"
    ":107EA00001C083E075D071C0823411F484E103C055\n"
    ":107EB000853419F485E08DD068C0853549F46FD0DC\n"
    ":107EC000D82E6DD08D2C912C982A880C991C5CC0D2\n"
    ":107ED000863521F484E07DD080E0E4CF843609F05B\n"
    ":107EE00036C05DD05CD0D82E5AD0C82EA12CBB2471\n"
    ":107EF000B39455D0F50181935F01DE12FACF61D0C2\n"
    ":107F0000F5E4CF1201C0FFCFF40117BFE89507B623\n"
    ":107F100000FCFDCFA401A0E0B1E02C911296CD01B0\n"
    ":107F20000197FC01808130E0382BFA01090107BF7D\n"
    ":107F3000E89511244E5F5F4FDA12EFCFF401F7BEE0\n"
    ":107F4000E89507B600FCFDCFE7BEE8951EC0843774\n"
    ":107F500071F425D024D0D82E22D033D05401F5018D\n"
    ":107F600085915F0115D0DA94D110F9CF0EC0853715\n"
    ":107F700039F427D08EE10CD085E90AD08FE092CF7A\n"
    ":107F8000813511F488E017D01CD080E101D07ACF80\n"
    ":107F90009091C00095FFFCCF8093C600089580911A\n"
    ":107FA000C00087FFFCCF8091C00084FD01C0A89570\n"
    ":107FB0008091C6000895E0E6F0E098E19083808328\n"
    ":107FC0000895EDDF803219F088E0F5DFFFCF84E11E\n"
    ":107FD000DFCFCF93C82FE3DFC150E9F7CF91F1CFC7\n"
    ":0C7FE000282E80E0E8DFE0E0FF27099495\n"
    ":0400000300007E007B\n"
    ":00000001FF\n"
  }
};
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

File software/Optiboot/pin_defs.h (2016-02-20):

/*
 * pin_defs.h
 * optiboot helper defining the default pin assignments (LED, SOFT_UART)
 * for the various chips that are supported.  This also has some ugly macros
 * for selecting among various UARTs and LED possibilities using command-line
 * defines like "UART=2 LED=B5"
 *
 * Copyright 2013-2015 by Bill Westfield.
 * Copyright 2010 by Peter Knight.
 * This software is licensed under version 2 of the Gnu Public Licence.
 * See optiboot.c for details.
 */

/*------------------------------------------------------------------------ */
#if defined(__AVR_ATmega168__) || defined(__AVR_ATmega168P__) || defined(__AVR_ATmega328__) || defined(__AVR_ATmega328P__) || defined(__AVR_ATmega328PB__) || defined(__AVR_ATmega88) || defined(__AVR_ATmega8__) || defined(__AVR_ATmega88__)
/*------------------------------------------------------------------------ */

/* Onboard LED is connected to pin PB5 in Arduino NG, Diecimila, and Duemilanove
 */
#if !defined(LED)
#define LED B5
#endif

//UART
#if !defined(U2X0)
#define U2X0 		U2X
#endif
#if !defined(RXC0)
#define RXC0 	  RXC
#endif
#if !defined(RXEN0)
#define RXEN0 	RXEN
#endif
#if !defined(TXEN0)
#define TXEN0 	TXEN
#endif
#if !defined(UDRE0)
#define UDRE0 	UDRE
#endif
#if !defined(UCSZ00)
#define UCSZ00 	UCSZ0
#endif
#if !defined(UCSZ01)
#define UCSZ01 	UCSZ1
#endif
#if !defined(FE0)
#define FE0 	  FE
#endif

//Timer
#if !defined(CS10)
#define CS10 	  CS0
#endif

/* Ports for soft UART */
//#ifdef SOFT_UART
#define UART_PORT   PORTD
#define UART_PIN    PIND
#define UART_DDR    DDRD
#define UART_TX_BIT 1
#define UART_RX_BIT 0
//#endif
#endif

/*
 * Handle devices with up to 4 uarts (eg m1280.)  Rather inelegantly.
 * Note that mega8/m32 still needs special handling, because ubrr is handled
 * differently.
 */
#if UART == 0
# define UART_SRA UCSR0A
# define UART_SRB UCSR0B
# define UART_SRC UCSR0C
# define UART_SRL UBRR0L
# define UART_UDR UDR0
#elif UART == 1
#if !defined(UDR1)
#error UART == 1, but no UART1 on device
#endif
# define UART_SRA UCSR1A
# define UART_SRB UCSR1B
# define UART_SRC UCSR1C
# define UART_SRL UBRR1L
# define UART_UDR UDR1
#elif UART == 2
#if !defined(UDR2)
#error UART == 2, but no UART2 on device
#endif
# define UART_SRA UCSR2A
# define UART_SRB UCSR2B
# define UART_SRC UCSR2C
# define UART_SRL UBRR2L
# define UART_UDR UDR2
#elif UART == 3
#if !defined(UDR1)
#error UART == 3, but no UART3 on device
#endif
# define UART_SRA UCSR3A
# define UART_SRB UCSR3B
# define UART_SRC UCSR3C
# define UART_SRL UBRR3L
# define UART_UDR UDR3
#endif

#if defined(__AVR_ATmega8__) || defined (__AVR_ATmega32__) || defined (__AVR_ATmega16__)
  //Name conversion R.Wiersma
  #define UCSR0A	UCSRA
  #define UDR0 		UDR
  #define UDRE0 	UDRE
  #define RXC0		RXC
  #define FE0		  FE
  #define TIFR1 	TIFR
  #define WDTCSR	WDTCR
#endif
#if defined (__AVR_ATmega32__) || defined (__AVR_ATmega16__)
  #define WDCE		WDTOE
#endif

/* Luminet support */
/*------------------------------------------------------------------------ */
#if defined(__AVR_ATtiny84__)
/*------------------------------------------------------------------------ */
/* Red LED is connected to pin PA4 */ 
#if !defined(LED)
#define LED         A4
#endif

/* Ports for soft UART - left port only for now. TX/RX on PA2/PA3 */
#ifdef SOFT_UART
#define UART_PORT   PORTA
#define UART_PIN    PINA
#define UART_DDR    DDRA
#define UART_TX_BIT 2
#define UART_RX_BIT 3
#endif
#endif

/*------------------------------------------------------------------------ */
/* Sanguino support (and other 40pin DIP cpus) */
#if defined(__AVR_ATmega644P__) || defined(__AVR_ATmega1284P__) || defined(__AVR_ATmega32__) || defined (__AVR_ATmega16__)
/*------------------------------------------------------------------------ */
/* Onboard LED is connected to pin PB0 on Sanguino */ 
#if !defined(LED)
#define LED         B0
#endif

/* Ports for soft UART */
#ifdef SOFT_UART
#define UART_PORT   PORTD
#define UART_PIN    PIND
#define UART_DDR    DDRD
#define UART_TX_BIT 1
#define UART_RX_BIT 0
#endif
#endif

/*------------------------------------------------------------------------ */
/* Mega support */
#if defined(__AVR_ATmega1280__)
/*------------------------------------------------------------------------ */
/* Onboard LED is connected to pin PB7 on Arduino Mega */ 
#if !defined(LED)
#define LED         B7
#endif

/* Ports for soft UART */
#ifdef SOFT_UART
#define UART_PORT   PORTE
#define UART_PIN    PINE
#define UART_DDR    DDRE
#define UART_TX_BIT 1
#define UART_RX_BIT 0
#endif
#endif

/*
 * ------------------------------------------------------------------------
 * A bunch of macros to enable the LED to be specifed as "B5" for bit 5
 * of port B, and similar.
 */

#define A0 0x100
#define A1 0x101
#define A2 0x102
#define A3 0x103
#define A4 0x104
#define A5 0x105
#define A6 0x106
#define A7 0x107

#define B0 0x200
#define B1 0x201
#define B2 0x202
#define B3 0x203
#define B4 0x204
#define B5 0x205
#define B6 0x206
#define B7 0x207
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

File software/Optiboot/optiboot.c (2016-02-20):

#define FUNC_READ 1
#define FUNC_WRITE 1
/**********************************************************/
/* Optiboot bootloader for Arduino                        */
/*                                                        */
/* http://optiboot.googlecode.com                         */
/*                                                        */
/* Arduino-maintained version : See README.TXT            */
/* http://code.google.com/p/arduino/                      */
/*  It is the intent that changes not relevant to the     */
/*  Arduino production envionment get moved from the      */
/*  optiboot project to the arduino project in "lumps."   */
/*                                                        */
/* Heavily optimised bootloader that is faster and        */
/* smaller than the Arduino standard bootloader           */
/*                                                        */
/* Enhancements:                                          */
/*   Fits in 512 bytes, saving 1.5K of code space         */
/*   Higher baud rate speeds up programming               */
/*   Written almost entirely in C                         */
/*   Customisable timeout with accurate timeconstant      */
/*   Optional virtual UART. No hardware UART required.    */
/*   Optional virtual boot partition for devices without. */
/*                                                        */
/* What you lose:                                         */
/*   Implements a skeleton STK500 protocol which is       */
/*     missing several features including EEPROM          */
/*     programming and non-page-aligned writes            */
/*   High baud rate breaks compatibility with standard    */
/*     Arduino flash settings                             */
/*                                                        */
/* Fully supported:                                       */
/*   ATmega168 based devices  (Diecimila etc)             */
/*   ATmega328P based devices (Duemilanove etc)           */
/*                                                        */
/* Beta test (believed working.)                          */
/*   ATmega8 based devices (Arduino legacy)               */
/*   ATmega328 non-picopower devices                      */
/*   ATmega644P based devices (Sanguino)                  */
/*   ATmega1284P based devices                            */
/*   ATmega1280 based devices (Arduino Mega)              */
/*                                                        */
/* Alpha test                                             */
/*   ATmega32                                             */
/*                                                        */
/* Work in progress:                                      */
/*   ATtiny84 based devices (Luminet)                     */
/*                                                        */
/* Does not support:                                      */
/*   USB based devices (eg. Teensy, Leonardo)             */
/*                                                        */
/* Assumptions:                                           */
/*   The code makes several assumptions that reduce the   */
/*   code size. They are all true after a hardware reset, */
/*   but may not be true if the bootloader is called by   */
/*   other means or on other hardware.                    */
/*     No interrupts can occur                            */
/*     UART and Timer 1 are set to their reset state      */
/*     SP points to RAMEND                                */
/*                                                        */
/* Code builds on code, libraries and optimisations from: */
/*   stk500boot.c          by Jason P. Kyle               */
/*   Arduino bootloader    http://arduino.cc              */
/*   Spiff's 1K bootloader http://spiffie.org/know/arduino_1k_bootloader/bootloader.shtml */
/*   avr-libc project      http://nongnu.org/avr-libc     */
/*   Adaboot               http://www.ladyada.net/library/arduino/bootloader.html */
/*   AVR305                Atmel Application Note         */
/*                                                        */

/* Copyright 2013-2015 by Bill Westfield.                 */
/* Copyright 2010 by Peter Knight.                        */
/*                                                        */
/* This program is free software; you can redistribute it */
/* and/or modify it under the terms of the GNU General    */
/* Public License as published by the Free Software       */
/* Foundation; either version 2 of the License, or        */
/* (at your option) any later version.                    */
/*                                                        */
/* This program is distributed in the hope that it will   */
/* be useful, but WITHOUT ANY WARRANTY; without even the  */
/* implied warranty of MERCHANTABILITY or FITNESS FOR A   */
/* PARTICULAR PURPOSE.  See the GNU General Public        */
/* License for more details.                              */
/*                                                        */
/* You should have received a copy of the GNU General     */
/* Public License along with this program; if not, write  */
/* to the Free Software Foundation, Inc.,                 */
/* 59 Temple Place, Suite 330, Boston, MA  02111-1307 USA */
/*                                                        */
/* Licence can be viewed at                               */
/* http://www.fsf.org/licenses/gpl.txt                    */
/*                                                        */
/**********************************************************/
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

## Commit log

2012-04-07 change to new UART defines
2012-12-10 changed drill size to 0.9mm
2015-01-01 added Arduino bootloader and extensions
2015-01-11 updated board group name
2015-01-27 added caterina bootloader with custom VID+PID
2015-01-27 added support for caterina with custom VID+PID
2015-01-28 added Tiny85 layout and schematics
    [Wattuino-Tiny85_v10.brd, Wattuino-Tiny85_v10.sch]
2015-02-01 updated USB vid+pid
2015-02-03 updated Tiny85/Nanite85
    [Wattuino-Nanite85_v10.brd, Wattuino-Nanite85_v10.sch]
2015-02-18 changed file names to lower case
2015-03-13 updated board support package
2015-05-06 updated layout and schematics
    [Wattuino-Nanite85_v10.brd, Wattuino-Nanite85_v10.sch]
2015-05-08 added Wattuino Uno
    [Wattuino-Uno_v10.brd, Wattuino-Uno_v10.sch]
2015-05-26 updated schematics
    [Wattuino-Nanite85_v10.brd, Wattuino-Nanite85_v10.sch, Wattuino-Uno_v10.brd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]
2015-06-01 added Tiny841/Nanite841
    [Wattuino-Nanite841_v10.brd, Wattuino-Nanite841_v10.sch]
2015-06-24 added Board Manager URL
2015-08-21 changed path structure
    [Wattuino-Nanite841_v10.brd, Wattuino-Nanite841_v10.sch, Wattuino-Nanite85_v10.brd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]
2016-02-23 added Wattuino Pro Mini PB
    [Wattuino-Pro-Mini-PB_v10.brd, Wattuino-Pro-Mini-PB_v10.sch]
2016-04-26 updated fuse settings
2016-05-03 updated boards
2016-05-03 updated fuses
2016-06-09 added Nanite841 rev 1.1
    [Wattuino-Nanite841_v11.brd, Wattuino-Nanite841_v11.sch]
2016-06-09 added Nanite85 rev 1.1
    [Wattuino-Nanite85_v11.brd, Wattuino-Nanite85_v11.sch]
2016-07-28 updated variant pin defines
2016-09-03 updated FTDI drivers to v2.12.18
2016-09-24 removed tools dependencies (not needed vor Arduino v1.6.12+)
2017-04-09 added samd boards
    [arduino_zero.cfg]
2017-05-23 BSP moved to github.com/watterott/Arduino-Boards
    [arduino_zero.cfg]
2017-06-07 added Wattuino RC v1.0
    [Wattuino-RC_v10.brd, Wattuino-RC_v10.sch]

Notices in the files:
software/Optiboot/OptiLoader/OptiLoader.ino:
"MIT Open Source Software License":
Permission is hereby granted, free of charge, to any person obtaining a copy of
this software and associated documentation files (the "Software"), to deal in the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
